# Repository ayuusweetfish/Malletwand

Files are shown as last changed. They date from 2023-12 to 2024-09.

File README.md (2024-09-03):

# Malletwand: the Pendulum as a Handheld Interface to Musical Timing

**Malletwand** is a handheld controller device in the form of a pendulum (a handle with a swinging bob), which can act as an input interface to the timing of musical playback.

We present this at [NIME](https://nime.org/) 2024 as a short paper ([PDF](paper/paper.pdf); video to-be-updated) in paper session 10, on Friday, 6 Sep.

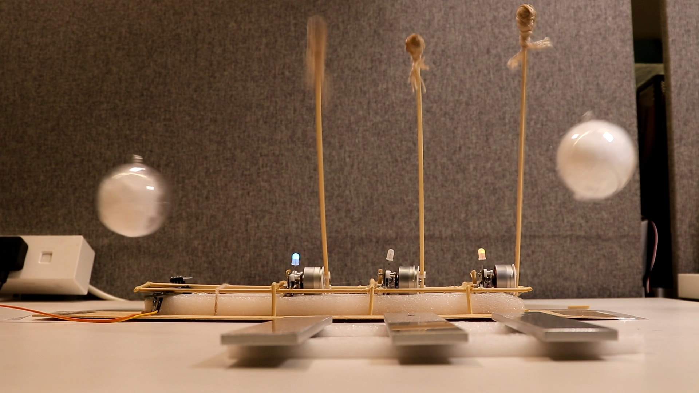
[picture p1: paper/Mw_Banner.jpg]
Banner image: the white balls of the controllers swinging in the air, in front of a prototype self-playing glockenspiel


## Contents

The following directories contain all the files for design and implementation (hardware, firmware, and mechanical).
- **wand/**: the handheld controller (the "Wand").
  - Hardware is a single PCB; firmware for the two controllers are in subdirectories **fw/** (the main one) and **fw_bob/** (the small one in the bob/ball) respectively.
- **mallet/**: one unit of the self-playing (robotic) glockenspiel instrument (the "Mallet").
- **mallet_central/**: the central unit for the instrument, mostly managing communications (both wireless and wired).

To use the files, the following software packages are required (versions for reference):
- Hardware: KiCad (7.0.10)
- Firmware: Arm GNU Toolchain (GCC 10.3.1), STM32Cube ('G0 1.5.0, 'L0 1.12.1), PlatformIO (6.1.15)
- Mechanical: FreeCAD (0.21.1), OpenSCAD (2021.01)

The following directories contain miscellaneous resources:
- **numerical/**: Numerical experiments for the filtering algorithms (EKF and ALS), implemented in Julia.
- **paper/**: The paper's LaTeX source and images.
- **testdrive/**: A testbed prototype for the sensors, created in the early days of development. Includes both hardware and firmware, and a desktop client to receive the BLE signals. Currently not well documented, but might be relevant for inspection (and visualisation?).
- **releases/**: Gerber files submitted to the PCB fabrication house.

## Licence
All content in this repository is distributed under CERN-OHL-S (CERN Open Hardware Licence Version 2, Strongly Reciprocal). See full text at **COPYING.txt** or [online](https://ohwr.org/cern_ohl_s_v2.txt).

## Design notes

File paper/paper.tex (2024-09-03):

% xelatex paper
% xelatex paper && bibtex paper && xelatex paper && xelatex paper

\documentclass{nime-alternate} % Uncomment when publishing final version

% Uncomment only one of the ones below
\usepackage{anonymize} 		   %Uncomment this line to publish
% \usepackage[blind]{anonymize}%Uncomment this line for blind review

\usepackage[utf8]{inputenc}

\usepackage{stfloats}
\usepackage{amsmath}
\usepackage{microtype}
\usepackage[hidelinks]{hyperref}

\begin{document}
\pretolerance=1000
\hyphenpenalty=100
\emergencystretch 1em

% --- Author Metadata here ---
\conferenceinfo{NIME'24,}{4--6 September, Utrecht, The Netherlands.}

\title{Malletwand: the Pendulum as a Handheld Interface to Musical Timing}

\label{key}
\numberofauthors{2}
\author{
\alignauthor
\anonymize{A.} \\
  \affaddr{\anonymize{Academy of Arts \& Design, Tsinghua University}}\\
  \affaddr{\anonymize{Beijing, China}}\\
  \email{\anonymize{claire@ayu.land}}
\alignauthor
\anonymize{H.} \\
  \affaddr{\anonymize{Academy of Arts \& Design, Tsinghua University}}\\
  \affaddr{\anonymize{Beijing, China}}\\
  \email{\anonymize{lihanxua22@mails.tsinghua.edu.cn}}
\and
\alignauthor
\anonymize{R.} \\
  \affaddr{\anonymize{Academy of Arts \& Design, Tsinghua University}}\\
  \affaddr{\anonymize{Beijing, China}}\\
  \email{\anonymize{wangrh22@mails.tsinghua.edu.cn}}
\alignauthor
\anonymize{H.} \\
  \affaddr{\anonymize{Academy of Arts \& Design, Tsinghua University}}\\
  \affaddr{\anonymize{Beijing, China}}\\
  \email{\anonymize{mhp@tsinghua.edu.cn}}
}
\date{6 February 2024}

\maketitle

\begin{figure*}[h!]
  \centering
  
  \caption{The Malletwand controllers with the prototype self-playing glockenspiel.}
  \label{fig:Banner}
\end{figure*}

\begin{abstract}
We devise and implement an interface in the form of a handheld pendulum device for manipulating the timing of musical playback. The physical properties of the pendulum make this interaction scheme steady and intuitive, and particularly suitable as an introductory means of musical engagement for untrained participants. We build a self-playing glockenspiel around this interface to demonstrate how our design encourages musical exploration and social play. We conclude by discussing potential extrapolations and integrations of the design in mobile and hybrid scenarios.
\end{abstract}
\keywords{Musical interface, pendulums, self-playing instruments, pose estimation, tactility, HCI}

\ccsdesc[500]{Applied computing~Sound and music computing}
\ccsdesc[300]{Human-centered computing~Interaction devices}
\ccsdesc[300]{Hardware~Sensor applications and deployments}
\printccsdesc

\section{Introduction}

Throughout our experience, we have always been able to capture the instinctive desire to actively and earnestly engage in music from those that have not had the advantage to experience music full-scale.
In our lasting endeavour to expand the reach of musically-meaningful interactive experiences, we set out on a search of an interaction scheme that is easy to understand and operate without musical expertise, while navigating the participant in sensible directions to manipulate the sounds to their own imagination, deepening their connection with the musical elements they have been presented with.

We settled on the periodic motion of the pendulum. The stability and self-recovering property of pendular motion make for a reliable framework of periodic musical time, i.e., tempo, or beats.

We devise and implement a controller interface, which we title the Malletwand, in the form of a handheld pendulum device (the ``wand''). By swinging the pendulum, the participant is able to feel and manipulate the speed of musical time, while the kinematic properties gently guide them through the tendency to keep a stable period, preventing excessive deviance from a steady tempo.

We imagine that this interface be paired with various types of musical actuators. For this report, we build a self-playing glockenspiel (the ``mallet'') operated by up to two such controllers in order to demonstrate how our design encourages musical exploration and social play.

The rest of the article is outlined as follows. We provide an overview of related work in various relevant fields before presenting the details of our design and implementation of the controller interface and the self-playing instrument. We go on to discuss potential extrapolations and integrations of the design in mobile and hybrid scenarios, some of which we plan as our future work. Algorithmic details are laid out in the appendix.

\section{Related work}

As we direct our design towards approachability for all levels of expertise, we look for intuitive universalities among human music, ideally natural kinesthetic and auditory stimuli that are processed and understood subconsciously. We directed our attention to the formation and perception of isochronal patterns based on the abundant argument that humans naturally tend to perceive time, and especially in the musical context, in cycles and patterns~\cite{Brower:Cog, Neisser_1976, Ravignani2016}. To paraphrase our forerunners, repeating cycles of time set the boundaries of our activities as well as form grounds on which we anticipate our sensory stimuli. Discussions went further to establish the metaphorical and cognitive interplay of our sense of time with embodied motion~\cite{Johnson_Larson_2003, Johnson_2008}.

Indeed, there have been a number of devices that manifest the link between periodic bodily movement and stable temporal patterns. Scrubbing is a standard technique for turntablists to manipulate the speed of sounds by rotating vinyl records. Hand-cranked musical boxes provide a more approachable way to drive the flow of music by one's own hands; although the Swedish band Wintergatan went as far as to build an entire machine, the Marble Machine, that turns the revolution of the manual crank into the progression of a musical piece~\cite{Rundle_Woollaston-Webber_2017}.

However, these devices share the common limitation that they require practice, or at least familarity with steady bodily movement, to prevent sounds from being distorted in the temporal domain. Laypeople tend to invoke unsteady musical time on such devices, rendering the music less understandable and aesthetically pleasing, while it remains unclear to them how they should refine their actions in the reasonable directions. Thus, they will not be able to get the most out of the tactile musical experience.

From another perspective, we are delighted to see novel musical devices that employ pendular motion or handheld physical controllers. Kugelschwung~\cite{Kugelschwung} is a digital musical instrument that relies on a set of pendulums mounted on a tabletop frame supplying control signals for soundscapes. Le Bâton~\cite{LeBaton} maps the chaotic behaviour of the triple pendulum into unpredictably varying electronic sounds. Gyrotyre~\cite{Gyrotyre}, on the other hand (no pun intended), is a handheld controller that maps oscillating signals from a gyroscope installed on a precessing wheel to various musical applications.

Still, these interfaces and instruments take larger physical forms and mainly aim at stage performances and/or dedicated experimental production setups. Our design adds to this ensemble a missing piece: a lightweight handheld controller interface that can be enjoyable and meaningful regardless of the participant's prior musical experience.

\section{The ``Wand''}

\subsection{Design Overview}
We first present the details of the handheld controller interface. It takes the form of a handle with a hanging bob (ball) that can freely swing and spin around, forming a pendulum. The participant swings the pendulum at their desired frequency while the bob's quasi-periodic motion is mapped to continuous musical time such that each fastest-moving point in a period corresponds to the start of a beat. (This point is usually perceived to be the ``central'' or the ``lowest'' point in simple pendulums, but since ours has an extra degree of freedom, i.e., is a spherical pendulum, this appointment needs to be extrapolated.) Such generated timing signals are wirelessly transmitted to an actuator, such as a self-playing instrument, that plays a piece of music according to the manipulated flow of musical time.

We add a few simple features to enrich the feedback and the interaction. Haptic feedback at beat onsets is provided by a vibration motor. A tri-colour LED is placed inside the bob that is flexible in its responses to interaction, e.g., it may indicate the changing beats by alternating tints or identify the voice by colour coding in the case of multiplayer interaction. Furthermore, the controller is intended to be normally at rest, so it is equipped with a tilt sensor that wakes up the entire circuit from sleep when the device is picked up by a participant. A single-pole, single-throw (SPST) switch allows the overall power to be turned off during times without participants.

\subsection{Construction}
We design customised electronics for all of our devices. In addition to the aforementioned components, the handle contains a lithium polymer (Li-Po) battery, a microcontroller, and a radio transceiver; the bob contains a separate low-power microcontroller and MEMS chips that form a 9-axis IMU (an accelerometer, a gyroscope, and a geomagnetometer). The complete structure is illustrated in Figure~\ref{fig:WandConstruction}.

\begin{figure*}[t!]
  \centering
  
  \caption{(a) Photo of the assembled circuit board before being cut. (b) Photo of the assembled wand with the casing and the bob. (c) Block diagram of the electronic components involved.}
  \label{fig:WandConstruction}
\end{figure*}

The board is fabricated as one, in order to ease soldering and debugging as we build the prototype. After testing is complete, we cut the board at the thin connection (in Figure~\ref{fig:WandConstruction}a) and connect the two parts with soldered thin wires (3 strands of 32 AWG, establishing an asynchronous USART connection). The handle part is glued inside a 3D-printed casing with the wires hanging down onto the bob part (Figure~\ref{fig:WandConstruction}b), which is inserted onto a holder made of polymeric foam glued in a translucent plastic sphere filled with down cotton. We add fishing wires to strengthen the connection and prevent the electric wires from excessive tension and fatigue.

\subsection{Estimation Algorithm}
All processing is done on the microcontroller device. The microcontroller we used, STM32G0, is an Arm Cortex-M0+ processor without a dedicated FPU, but our complete algorithm runs well within its 64 MHz system clock with software floating-point arithmetic.

The algorithm requires an initial reference frame calibration, run once after assembly. An ensemble of filters is then employed to process the sensor signals. We introduce these steps respectively. To keep our description concise, we defer all of the mathematical details to Appendix~\ref{appendix:signal-processing}.

\subsubsection{Reference frame calibration}
After assembly, the tilted orientation of the circuit board inside the bob should be compensated for.

The calibration is initiated by a manually-issued wireless radio signal. The operator is then expected to hold the handle and let the bob stay stationary for a short while. Signals from the accelerometer are continuously monitored until they reach a sufficiently low deviation throughout a fixed time window of 3 seconds. This yields an axis vector that acts as the reference for future motion estimation from sensor readings which is saved in the persistent flash storage of the microcontroller. For details, please refer to Appendix~\ref{appendix:calib-ori}.

\subsubsection{Magnetometer calibration}
As our algorithm relies on the geomagnetometer to improve the accuracy of pose estimation, the distortion of the ambient magnetic field should also be compensated. Since indoor environments contain prominent and variable magnetic interference, this calibration is done in real time during operation. This works by continuously collecting the readings of the magnetometer and finding an ellipsoid fit that tries to distort the collected data in the form of 3D vectors onto a unit sphere. We employ the adjusted least squares estimator introduced by \cite{Markovsky_2004_ALS} with complementary steps by \cite{Renaudin2010}.

\subsubsection{Motion signal processing}
Our IMU produces readings at a sampling rate of 100 Hz, and the filtering algorithms run at the same rate. At each time step, we first estimate the facing of the bob through a complementary filter, inspired by~\cite{Min_Complementary}, combining signals from the gyroscope and the magnetometer. The result is turned into a rotational transform that cancels out the bob's rotation around its own axis. Sensor readings adjusted by this transform are then fed into an extended Kalman filter (EKF) that estimates the trajectory of the bob in 3D space, and more importantly, its current phase within the period of motion. This is the value that gets interpreted as the driving signal of musical time, and is transmitted to the actuator.

A confidence indicator is derived from the Frobenius norm of the estimation covariance matrix in the EKF. This value is used to avoid muddled time progression when the motion is not stably periodic, e.g., during the first few seconds since the beginning of interaction.

\section{The ``Mallets''}

\begin{figure*}[bh!]
  \centering
  
  \caption{(a) Overall photo of the instrument. (b) Close-up of a single sub-unit. (c) Block diagram of the electronic components involved.}
  \label{fig:MalletConstruction}
\end{figure*}

\subsection{Design Overview}
Our self-playing instrument is a robotic glockenspiel. We use a 3-key prototype for demonstrative purposes, but an extension of register requires no change in implementation.

The instrument is accompanied by two Malletwand controllers and can operate in both solo and co-operative mode. Signals received from the controllers drive the musical time in a preprogrammed piece, similar to a musical box. Co-operative mode is entered by two controllers being operated simultaneously, where each controller corresponds to one voice (part) indicated by colours of the lights. The music only progresses when the motion of the two are roughly in synchronisation.

\subsection{Construction}
\subsubsection{Keys}
The keys are laser-cut from aluminum of 5 mm thickness. We chose aluminum instead of an alloy since we would like a mellower timbre. Prior to production, we ordered a small number of samples from the fabricator to determine the acoustic characteristics of the material. The resonant frequency of a vibrating metal bar is inversely proportional to the square root of its length; we thus calculate the desired lengths according to equal-temperament tuning, create the blueprints programmatically in OpenSCAD and send them for fabrication.

\subsubsection{Electronics}
The electronics of the instrument comprise a main unit and multiple sub-units, one for each key. The main unit is responsible for the communication with the controller(s) as well as the delivery of power and control signals to the sub-units. Each sub-unit has a small brushless DC (BLDC) motor that holds a yarn mallet, fixed onto a circuit board bearing a magnetic encoder, a tri-colour LED, and a microcontroller carrying out vector control. The entire device is powered by a single DC supply between 9~V and 25~V into the main unit. The complete structure is illustrated in Figure~\ref{fig:MalletConstruction}.

We choose I\textsuperscript{2}C as the communication protocol, requiring only two electrical signals for multiple parallel devices. We use an I\textsuperscript{2}C accelerator chip on the main unit to mitigate the rise time issue due to increased bus capacitance of long transmission wires.

\subsubsection{Mechanical and miscellaneous}
We fix all units (both the main one and sub-units) onto polymeric foam which is glued onto a thin wooden board that serves as the base. Slots created on the foam hold the units as well as the electrical lines. We glue an extra frame made of wooden sticks around the foam to improve stability.

The mechanical parts for the fixation of motors and mallets are 3D-printed in PLA and installed with screws. Yarn on the mallets is manually wrapped around a wooden core and slightly melted with a lighter in order to tighten it.

\subsection{Performance}
During operation, the glockenspiel plays a tune as the pendulums swing back and forth. The tempo of the music adjusts to the period of pendular motion. Haptic feedback and lights on both the bob and the keys add tactility and visualisation to the embodied musical experience. Figure~\ref{fig:Banner} is a photo of the instrument in action.

Please refer to the demonstration video for a performance recording.

\section{Discussion}

\subsection{The Experience of Malletwand}
Our design accomplished our initial goals. The algorithms yield a reliable estimation of motion, successfully running the glockenspiel through a tune steadily with little external intervention on the pendulum, while being able to respond reasonably fast to changes in motion (within 1\textasciitilde{}2 swings). We enjoyed our own work.

Our pilot study with outside participants was preliminary, but sufficient to bring forth a few insights. We confirmed that the pendulum-based interface is appreciated for its accuracy and ease of use. First-time users might not instantly figure out how to reliably manipulate the speed (period) of the pendulum, but were able to do so with their own exploration or with a hint. Since participants were able to quickly grasp the mapping logic and its control, musical exploration was instantly opened up to them. Participants tended to experiment with extremes before resorting to a steady tempo, trying gentler articulations. They considered the interaction intuitive and manageable, and reported being generally successful in their pursuit of musical engagement and expression.

Social play is encouraged through the attempts to synchronise between the duo. This resembles the experience of musicians in ensembles, orchestras, or bands, and is appreciated by such practitioners. However, we notice that this is a rare and precious chance for participants with less musical experiences, and we hope to bring such meaningful and joyful activities to their reach through our design. We are still yet to conduct more extensive studies with such participants.

One major shortcoming of the co-operative mode is the difficulty to synchronise the phases between the duo, due to inertia preventing quick changes in speed, even more so regarding phase and position. This has the benefit of extending conversations and explorations between participants, but the less experienced of them might not figure out effective ways quickly and intuitively. In this regard, we are considering improving on the co-operative play mode, either by revamping the interaction rules or by extra hints in the form of synchronised haptic feedback or textual hints.

\subsection{Extrapolations and Future Work}
As we have written in the Introduction section, we imagine that this interface not be limited to our glockenspiel instrument. Any device that plays music can employ a pendulum interface to invite participants into musical time. Hybrid formats, including projections and mappings, or musical devices remotely incited beyond kilometers, open doors to tactility in a hybrid world.

Other musical features or temporal formats, or even spatial expositions, may be involved as well. What about an installation that gives procedurally generated sounds? What about a film? A dance? A video game where cats chase the wand? A revolving kaleidoscope or a planetarium?

The estimation algorithms in the pendulum enable it to act as a standalone sensor, adding to the toolkit of digital artistic expression. What about an electronic mimicry of a windbell? A big hanging simulated telescope? A sparkling earring?

Another possible extrapolation lies in the mobile scenario. The sensors we used are standard in today's smartphones, and relevant APIs are readily available on modern web browsers. Thus, with the processing algorithms ported to JavaScript, websites will be able to create novel interactive experiences without special equipment, simply by asking the visitor to put their phone in a holder, attach a string, and swing it to their liking. What about such a musical box? We leave all these for the reader as exercises while we try our hands on a few.

\section{Conclusion}
Malletwand is our first step in spreading the enjoyability of music through a tactile medium. It is to our delight to have implemented the system and seeing it bear the unique approachability and adaptability to varied levels of musical expertise, adding to the state-of-the-art repertoire of physical-system controller interfaces. We realise that this interface has the potential to adapt to more instruments and scenarios, and put forward what we have envisaged. We share our work in the hope that our methods and insights can be useful to those who share the aspirations with us.

\section{Ethical Statement}
This research does not involve processes or experiments that might raise ethical concerns. In addition, the authors have made conscious efforts to abide by the NIME ethical guidelines.

\section{Acknowledgments}
We would like to thank the anonymous reviewers for their valuable feedback. We would like to extend our gratitude towards Yao Zhihao for the enthusiastic help in handicraft work; and to Dr Mier, for offering aid in mathematical concepts. A special acknowledgement goes to Tsinghua University Symphonic Band, without which this motif would not have developed.

\bibliographystyle{abbrv}
\bibliography{nime-references} 

\appendix
\section{Details of the Signal Processing Algorithms}
\label{appendix:signal-processing}
We try to outline the mathematical derivations of the algorithms. For details, please refer to the source code.

\subsection{Calibration}
\subsubsection{Reference frame}
\label{appendix:calib-ori}
An accelerometer reading is a 3-dimensional vector. When a sufficiently low variation of readings is achieved during calibration, their average vector is normalized and taken as the reference axis $\mathbf{u}$. We find a quaternion $\mathbf{q}$ that rotates this vector to the $+z$ unit vector, $\mathbf{z}^+ = \begin{bmatrix} 0 & 0 & 1 \end{bmatrix}^\mathsf{T}$. This is achieved by setting $\mathbf{q}_1 = \begin{bmatrix} \mathbf{u} \times \mathbf{z^+} & (1 + \mathbf{u} \cdot \mathbf{z^+}) \end{bmatrix}$ and $\mathbf{q} = \mathbf{q}_1 \mathbin{\mathop{/}} \lvert \mathbf{q}_1 \rvert$.

This quaternion $\mathbf{q}$ transforms the reference frame of the accelerometer such that the $xy$ plane corresponds to the local ground, whose normal vector is the $z$ axis. The rotation specified by $\mathbf{q}$ is applied to future raw accelerometer readings $\tilde{\mathbf{a}}$ and gyroscope readings $\tilde{\mathbf{g}}$, assuming that their reference frames are aligned, to yield a carlibrated 6-axis reading:
$\mathbf{a} = \mathbf{q} \tilde{\mathbf{a}} \mathbf{q}^{-1}$, $\mathbf{g} = \mathbf{q} \tilde{\mathbf{g}} \mathbf{q}^{-1}$.

\subsubsection{Magnetometer}
\label{appendix:calib-mag}
This task can be formulated as follows: given a set of 3-dimensional vectors $\{ \tilde{\mathbf{m}}_i \}$, find an affine transform $(\mathbf{Q}, \mathbf{o})$ such that the set of $\{\mathbf{Q} \tilde{\mathbf{m}}_i + \mathbf{o}\}$ best fits onto a unit sphere.

We follow the method of \cite{Renaudin2010}, employing the ALS estimator in \cite{Markovsky_2004_ALS} to find a fit $(\mathbf{A}, \mathbf{c})$ to the set of equations
$(\tilde{\mathbf{m}}_i - \mathbf{c})^\mathsf{T} \mathbf{A} (\tilde{\mathbf{m}}_i - \mathbf{c}) = 1$
and then calculating an inverse transform that converts this ellipsoid back to the unit sphere.

Since the ALS estimator only requires an accumulated matrix $\mathbf{\Psi}$ and not the individual values of $\tilde{\mathbf{m}}_i$, we are able to carry out the calculation continuously with constant rather than linear memory consumption.

\subsection{Estimation}
\subsubsection{Facing}
\label{appendix:est-facing}
We treat the 2-dimensional orientation angle on the $xy$ plane as the value being estimated. The calibrated magnetometer provides a proportional signal $\varphi$, while the calibrated gyroscope provides a derivative signal $\dot\varphi$.
The input signals are given by $\varphi = -\mathop{\mathrm{arctan}} \frac {\mathbf{m}_y} {\mathbf{m}_x}$ and $\dot\varphi = \mathrm{d}{\mathbf{g}_y} \mathbin{\mathop{/}} \mathrm{d}t$. Here $\mathbf{m}$ is the calibrated and aligned magnetometer reading,
\begin{equation*}\label{eqn:est-facing}
\mathbf{m} = \mathbf{q} \ (\mathbf{Q}\tilde{\mathbf{m}} + \mathbf{o}) \ \mathbf{q}^{-1}\text{,}
\end{equation*}
and $\mathbf{g}$ is the calibrated gyroscope reading as is mentioned in section~\ref{appendix:calib-ori}.

Following the design in~\cite{Min_Complementary}, we construct a complementary filter by the transfer equation
\begin{equation*}
\begin{split}
& \hat{\varphi} = \frac 1 {s^2 + k_\mathrm{p} s + k_\mathrm{i}} \left( s \dot\varphi + (k_\mathrm{p} s + k_\mathrm{i}) \varphi \right) \text{,} \\
& k_\mathrm{p} = \frac {\omega_0} {Q_\mathrm{P}},\qquad k_\mathrm{i} = \omega_0^2\text{.}
\end{split}
\end{equation*}
This filter yields an estimation $\hat{\varphi}$ balancing between the two signals.
We fix the pole quality factor as $Q_\mathrm{P} = 1 \mathbin{\mathop{/}} \sqrt{2}$ and empirically tune the corner frequency at $\omega_0 = 24\ \text{rad/s} \approx 3.8\ \text{Hz}$.

\subsubsection{Motion}
\label{appendix:est-motion}
In the extended Kalman filter we formulate the state vector as $\mathbf{x} = \begin{bmatrix} \omega & A & \theta & B & \phi \end{bmatrix}^\mathsf{T}$, charactising an elliptical orbit around the origin --- the ideal observation $\mathbf{z} = \begin{bmatrix} A \cos \theta & B \cos (\theta + \phi) \end{bmatrix}^\mathsf{T}$ is compared against the gyroscope readings adjusted by the facing estimation,
\begin{equation*}
\begin{split}
\hat{\mathbf{g}}' &= \mathbf{r}_{z, \theta} \hat{\mathbf{g}} \mathbf{r}_{z, \theta}^{-1} \\
\text{where}\quad \mathbf{r}_{z, \theta} &= \begin{bmatrix} 0 & 0 & \sin \frac \theta 2 & \cos \frac \theta 2 \end{bmatrix}
\text{,}
\end{split}
\end{equation*}
projected onto the $xy$ plane. Varying $\theta$ over $[0, 2\pi)$ traces out an elliptic trajectory of this point and $\theta$ is the current phase within the period. $\omega$ is the rate of change of phase, $\mathrm{d}{\theta} \mathbin{\mathop{/}} \mathrm{d}t$, thus the prediction function is
\begin{equation*}
f(\mathbf{x}) = \begin{bmatrix} \omega & A & \theta + \omega \Delta t & B & \phi \end{bmatrix}^\mathsf{T}\text{.}
\end{equation*}
The process noise covariance matrix is set to be a diagonal matrix with the first entry prominently larger than the others, since $\omega$ is actively changed by the participant. % $A, \theta, B, \phi$ are assigned smaller process noise variances so that the filter does not get stuck in a local optimum where all parameters oscillate, altogether stopping the steady progress of phase.

After the estimations of $A, \theta, B, \phi$ are obtained, we find the corresponding parameter $\theta$ at the major axis (which is also the fastest-moving point) by
\begin{equation*}
\theta_0 = \frac 1 2 \mathop{\mathrm{arctan}} \frac {A^2 + B^2 \cos 2\phi} {B^2 \sin 2\phi} + \frac 1 4 \pi\text{,}
\end{equation*}
and report the difference $\theta - \theta_0$ as the final output, so that an output phase of zero aligns with this fastest-moving point.

\section{Source Repository}
All of our design files (printed circuit board assemblies, mechanical models) and source code, as well as extended documentation and demonstrations, are published at \newline \anonymize{\texttt{https://github.com/ayuusweetfish/Malletwand}}.

\end{document}

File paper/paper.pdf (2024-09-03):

# Malletwand: the Pendulum as a Handheld Interface to Musical Timing

A.

### Academy of Arts & Design, Tsinghua University Beijing, China claire@ayu.land

H.

### Academy of Arts & Design, Tsinghua University Beijing, China lihanxua22@mails.tsinghua.edu.cn

R.

### Academy of Arts & Design, Tsinghua University Beijing, China wangrh22@mails.tsinghua.edu.cn

H.

### Academy of Arts & Design, Tsinghua University Beijing, China mhp@tsinghua.edu.cn

## ABSTRACT

We devise and implement an interface in the form of a handheld pendulum device for manipulating the timing of musical playback. The physical properties of the pendulum make this interaction scheme steady and intuitive, and particularly suitable as an introductory means of musical engagement for untrained participants. We build a self-playing glockenspiel around this interface to demonstrate how our design encourages musical exploration and social play. We conclude by discussing potential extrapolations and integrations of the design in mobile and hybrid scenarios.

## Author Keywords

Musical interface, pendulums, self-playing instruments, pose estimation, tactility, HCI

## CCS Concepts

•Applied computing → Sound and music computing; •Humancentered computing → Interaction devices; •Hardware → Sensor applications and deployments;

## 1. INTRODUCTION

Throughout our experience, we have always been able to capture the instinctive desire to actively and earnestly engage in music from those that have not had the advantage to experience music full-scale. In our lasting endeavour to expand the reach of musically-meaningful interactive experiences, we set out on a search of an interaction scheme that is easy to understand and operate without musical expertise, while navigating the participant in sensible directions to manipulate the sounds to their own imagination, deepening their connection with the musical elements they have been presented with.
We settled on the periodic motion of the pendulum. The stability and self-recovering property of pendular motion

Licensed under a Creative Commons Attribution 4.0 International License (CC BY 4.0). Copyright remains with the author(s).
NIME’24, 4–6 September, Utrecht, The Netherlands.

make for a reliable framework of periodic musical time, i.e., tempo, or beats.
We devise and implement a controller interface, which we title the Malletwand, in the form of a handheld pendulum device (the “wand”). By swinging the pendulum, the participant is able to feel and manipulate the speed of musical time, while the kinematic properties gently guide them through the tendency to keep a stable period, preventing excessive deviance from a steady tempo.
We imagine that this interface be paired with various types of musical actuators. For this report, we build a self-playing glockenspiel (the “mallet”) operated by up to two such controllers in order to demonstrate how our design encourages musical exploration and social play.
The rest of the article is outlined as follows. We provide an overview of related work in various relevant fields before presenting the details of our design and implementation of the controller interface and the self-playing instrument. We go on to discuss potential extrapolations and integrations of the design in mobile and hybrid scenarios, some of which we plan as our future work. Algorithmic details are laid out in the appendix.

## 2. RELATED WORK

As we direct our design towards approachability for all levels of expertise, we look for intuitive universalities among human music, ideally natural kinesthetic and auditory stimuli that are processed and understood subconsciously. We directed our attention to the formation and perception of isochronal patterns based on the abundant argument that humans naturally tend to perceive time, and especially in the musical context, in cycles and patterns [1, 7, 8]. To paraphrase our forerunners, repeating cycles of time set the boundaries of our activities as well as form grounds on which we anticipate our sensory stimuli. Discussions went further to establish the metaphorical and cognitive interplay of our sense of time with embodied motion [4, 3].
Indeed, there have been a number of devices that manifest the link between periodic bodily movement and stable temporal patterns. Scrubbing is a standard technique for turntablists to manipulate the speed of sounds by rotating vinyl records. Hand-cranked musical boxes provide a more approachable way to drive the flow of music by one’s own hands; although the Swedish band Wintergatan went as far as to build an entire machine, the Marble Machine, that turns the revolution of the manual crank into the progression of a musical piece [10].
However, these devices share the common limitation that they require practice, or at least familarity with steady


Figure 1: The Malletwand controllers with the prototype self-playing glockenspiel.

bodily movement, to prevent sounds from being distorted in the temporal domain. Laypeople tend to invoke unsteady musical time on such devices, rendering the music less understandable and aesthetically pleasing, while it remains unclear to them how they should refine their actions in the reasonable directions. Thus, they will not be able to get the most out of the tactile musical experience.
From another perspective, we are delighted to see novel musical devices that employ pendular motion or handheld physical controllers. Kugelschwung [2] is a digital musical instrument that relies on a set of pendulums mounted on a tabletop frame supplying control signals for soundscapes. Le Bˆaton [12] maps the chaotic behaviour of the triple pendulum into unpredictably varying electronic sounds. Gyrotyre [11], on the other hand (no pun intended), is a handheld controller that maps oscillating signals from a gyroscope installed on a precessing wheel to various musical applications.
Still, these interfaces and instruments take larger physical forms and mainly aim at stage performances and/or dedicated experimental production setups. Our design adds to this ensemble a missing piece: a lightweight handheld controller interface that can be enjoyable and meaningful regardless of the participant’s prior musical experience.

## 3. THE “WAND”

## 3.1 Design Overview

We first present the details of the handheld controller interface. It takes the form of a handle with a hanging bob (ball) that can freely swing and spin around, forming a pendulum. The participant swings the pendulum at their desired frequency while the bob’s quasi-periodic motion is mapped to continuous musical time such that each fastest-moving point in a period corresponds to the start of a beat. (This point is usually perceived to be the “central” or the

“lowest” point in simple pendulums, but since ours has an extra degree of freedom, i.e., is a spherical pendulum, this appointment needs to be extrapolated.) Such generated timing signals are wirelessly transmitted to an actuator, such as a self-playing instrument, that plays a piece of music according to the manipulated flow of musical time.
We add a few simple features to enrich the feedback and the interaction. Haptic feedback at beat onsets is provided by a vibration motor. A tri-colour LED is placed inside the bob that is flexible in its responses to interaction, e.g., it may indicate the changing beats by alternating tints or identify the voice by colour coding in the case of multiplayer interaction. Furthermore, the controller is intended to be normally at rest, so it is equipped with a tilt sensor that wakes up the entire circuit from sleep when the device is picked up by a participant. A single-pole, single-throw (SPST) switch allows the overall power to be turned off during times without participants.

## 3.2 Construction

We design customised electronics for all of our devices. In addition to the aforementioned components, the handle contains a lithium polymer (Li-Po) battery, a microcontroller, and a radio transceiver; the bob contains a separate lowpower microcontroller and MEMS chips that form a 9-axis IMU (an accelerometer, a gyroscope, and a geomagnetometer). The complete structure is illustrated in Figure 2. The board is fabricated as one, in order to ease soldering and debugging as we build the prototype. After testing is complete, we cut the board at the thin connection (in Figure 2a) and connect the two parts with soldered thin wires (3 strands of 32 AWG, establishing an asynchronous USART connection). The handle part is glued inside a 3D-printed casing with the wires hanging down onto the bob part (Figure 2b), which is inserted onto a holder made of polymeric foam glued in a translucent plastic sphere filled

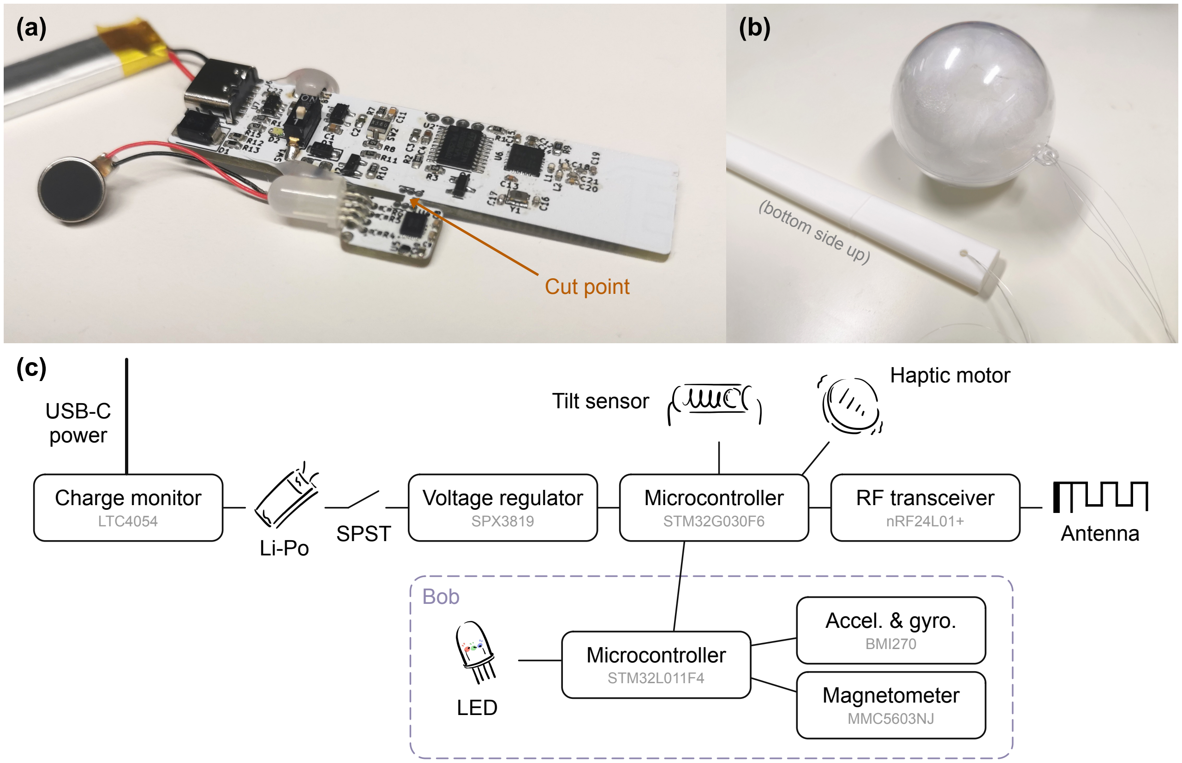
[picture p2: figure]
Microcontroller; STM32G030F6; Charge monitor; LTC4054; RF transceiver; nRF24L01+; Accel. & gyro.; BMI270; Magnetometer; MMC5603NJ; Voltage regulator SPX3819 SPST Li-Po; LED; Haptic motor; Tilt sensor; Cut point; USB-C power; Bob; STM32L011F4; Antenna; (bot om side up)

Figure 2: (a) Photo of the assembled circuit board before being cut. (b) Photo of the assembled wand with the casing and the bob. (c) Block diagram of the electronic components involved.

with down cotton. We add fishing wires to strengthen the connection and prevent the electric wires from excessive tension and fatigue.

## 3.3 Estimation Algorithm

All processing is done on the microcontroller device. The microcontroller we used, STM32G0, is an Arm Cortex-M0+ processor without a dedicated FPU, but our complete algorithm runs well within its 64 MHz system clock with software floating-point arithmetic.
The algorithm requires an initial reference frame calibration, run once after assembly. An ensemble of filters is then employed to process the sensor signals. We introduce these steps respectively. To keep our description concise, we defer all of the mathematical details to Appendix A.

### 3.3.1 Reference frame calibration

After assembly, the tilted orientation of the circuit board inside the bob should be compensated for.
The calibration is initiated by a manually-issued wireless radio signal. The operator is then expected to hold the handle and let the bob stay stationary for a short while. Signals from the accelerometer are continuously monitored until they reach a sufficiently low deviation throughout a fixed time window of 3 seconds. This yields an axis vector that acts as the reference for future motion estimation from sensor readings which is saved in the persistent flash storage of the microcontroller. For details, please refer to Appendix A.1.1.

### 3.3.2 Magnetometer calibration

As our algorithm relies on the geomagnetometer to improve the accuracy of pose estimation, the distortion of the ambient magnetic field should also be compensated. Since indoor environments contain prominent and variable magnetic interference, this calibration is done in real time during operation. This works by continuously collecting the readings of the magnetometer and finding an ellipsoid fit that tries to distort the collected data in the form of 3D vectors onto a unit sphere. We employ the adjusted least squares estimator introduced by [5] with complementary steps by [9].

### 3.3.3 Motion signal processing

Our IMU produces readings at a sampling rate of 100 Hz, and the filtering algorithms run at the same rate. At each time step, we first estimate the facing of the bob through a complementary filter, inspired by [6], combining signals from the gyroscope and the magnetometer. The result is turned into a rotational transform that cancels out the bob’s rotation around its own axis. Sensor readings adjusted by this transform are then fed into an extended Kalman filter (EKF) that estimates the trajectory of the bob in 3D space, and more importantly, its current phase within the period of motion. This is the value that gets interpreted as the driving signal of musical time, and is transmitted to the actuator.
A confidence indicator is derived from the Frobenius norm of the estimation covariance matrix in the EKF. This value is used to avoid muddled time progression when the motion is not stably periodic, e.g., during the first few seconds since the beginning of interaction.

## 4. THE “MALLETS”

## 4.1 Design Overview

Our self-playing instrument is a robotic glockenspiel. We use a 3-key prototype for demonstrative purposes, but an extension of register requires no change in implementation. The instrument is accompanied by two Malletwand controllers and can operate in both solo and co-operative mode. Signals received from the controllers drive the musical time in a preprogrammed piece, similar to a musical box. Co-operative mode is entered by two controllers being operated simultaneously, where each controller corresponds to one voice (part) indicated by colours of the lights. The music only progresses when the motion of the two are roughly in synchronisation.

## 4.2 Construction

### 4.2.1 Keys

The keys are laser-cut from aluminum of 5 mm thickness. We chose aluminum instead of an alloy since we would like a mellower timbre. Prior to production, we ordered a small number of samples from the fabricator to determine the acoustic characteristics of the material. The resonant frequency of a vibrating metal bar is inversely proportional to the square root of its length; we thus calculate the desired lengths according to equal-temperament tuning, create the blueprints programmatically in OpenSCAD and send them for fabrication.

### 4.2.2 Electronics

The electronics of the instrument comprise a main unit and multiple sub-units, one for each key. The main unit is responsible for the communication with the controller(s) as well as the delivery of power and control signals to the sub-units. Each sub-unit has a small brushless DC (BLDC) motor that holds a yarn mallet, fixed onto a circuit board bearing a magnetic encoder, a tri-colour LED, and a microcontroller carrying out vector control. The entire device is powered by a single DC supply between 9 V and 25 V into the main unit. The complete structure is illustrated in Figure 3.
We choose I²C as the communication protocol, requiring only two electrical signals for multiple parallel devices. We use an I²C accelerator chip on the main unit to mitigate the rise time issue due to increased bus capacitance of long transmission wires.

### 4.2.3 Mechanical and miscellaneous

We fix all units (both the main one and sub-units) onto polymeric foam which is glued onto a thin wooden board that serves as the base. Slots created on the foam hold the units as well as the electrical lines. We glue an extra frame made of wooden sticks around the foam to improve stability. The mechanical parts for the fixation of motors and mallets are 3D-printed in PLA and installed with screws. Yarn on the mallets is manually wrapped around a wooden core and slightly melted with a lighter in order to tighten it.

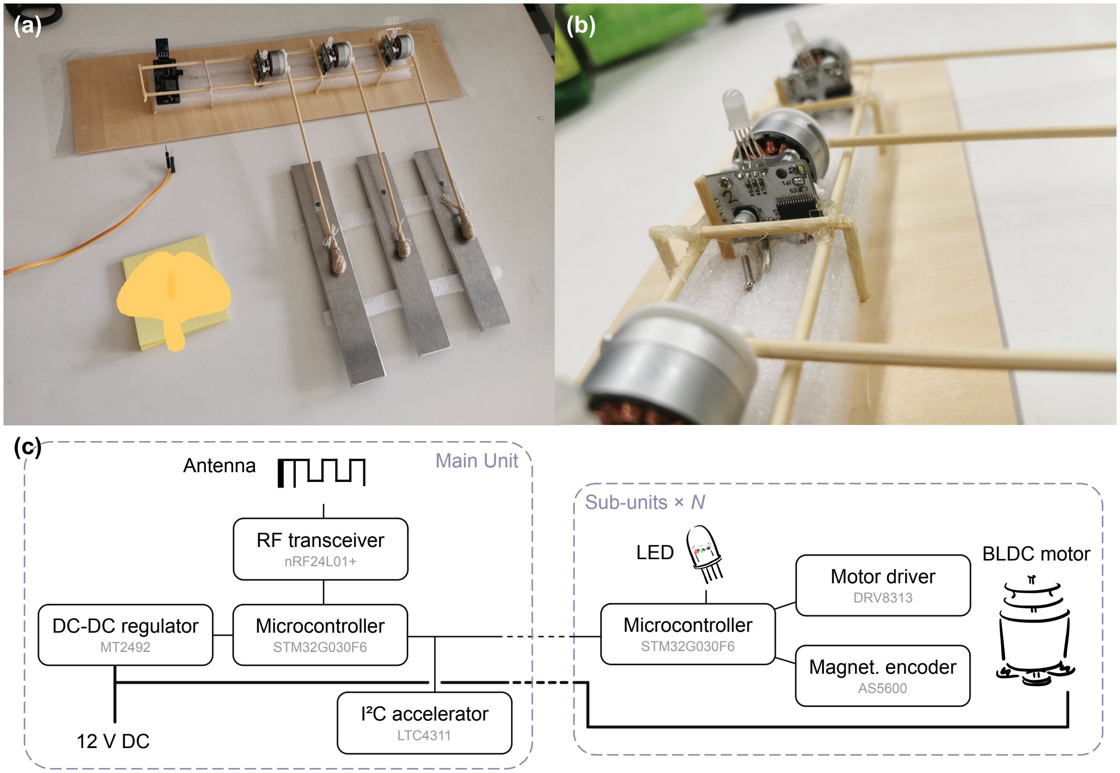
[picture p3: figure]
Microcontroller; STM32G030F6; RF transceiver; nRF24L01+; DC-DC regulator; I²C accelerator; LTC4311; Antenna; Motor driver; DRV8313; Magnet. encoder; LED; Sub-units × N; BLDC motor; Main Unit (c)

Figure 3: (a) Overall photo of the instrument. (b) Close-up of a single sub-unit. (c) Block diagram of the electronic components involved.

## 4.3 Performance

During operation, the glockenspiel plays a tune as the pendulums swing back and forth. The tempo of the music adjusts to the period of pendular motion. Haptic feedback and lights on both the bob and the keys add tactility and visualisation to the embodied musical experience. Figure 1 is a photo of the instrument in action.
Please refer to the demonstration video for a performance recording.

## 5. DISCUSSION

## 5.1 The Experience of Malletwand

Our design accomplished our initial goals. The algorithms yield a reliable estimation of motion, successfully running the glockenspiel through a tune steadily with little external intervention on the pendulum, while being able to respond reasonably fast to changes in motion (within 1˜2 swings). We enjoyed our own work.
Our pilot study with outside participants was preliminary, but sufficient to bring forth a few insights. We confirmed that the pendulum-based interface is appreciated for its accuracy and ease of use. First-time users might not instantly figure out how to reliably manipulate the speed (period) of the pendulum, but were able to do so with their own exploration or with a hint. Since participants were able to quickly grasp the mapping logic and its control, musical exploration was instantly opened up to them. Participants tended to experiment with extremes before resorting to a steady tempo, trying gentler articulations. They considered the interaction intuitive and manageable, and reported being generally successful in their pursuit of musical engagement and expression.
Social play is encouraged through the attempts to synchronise between the duo. This resembles the experience of musicians in ensembles, orchestras, or bands, and is appreciated by such practitioners. However, we notice that this is a rare and precious chance for participants with less musical experiences, and we hope to bring such meaningful and joyful activities to their reach through our design. We are still yet to conduct more extensive studies with such participants.
One major shortcoming of the co-operative mode is the difficulty to synchronise the phases between the duo, due to inertia preventing quick changes in speed, even more so regarding phase and position. This has the benefit of extending conversations and explorations between participants, but the less experienced of them might not figure out effective ways quickly and intuitively. In this regard, we are considering improving on the co-operative play mode, either by revamping the interaction rules or by extra hints in the form of synchronised haptic feedback or textual hints.

## 5.2 Extrapolations and Future Work

As we have written in the Introduction section, we imagine that this interface not be limited to our glockenspiel instrument. Any device that plays music can employ a pendulum interface to invite participants into musical time. Hybrid formats, including projections and mappings, or musical devices remotely incited beyond kilometers, open doors to tactility in a hybrid world.
Other musical features or temporal formats, or even spatial expositions, may be involved as well. What about an installation that gives procedurally generated sounds? What about a film? A dance? A video game where cats chase the wand? A revolving kaleidoscope or a planetarium? The estimation algorithms in the pendulum enable it to act as a standalone sensor, adding to the toolkit of digital artistic expression. What about an electronic mimicry of a windbell? A big hanging simulated telescope? A sparkling earring?
Another possible extrapolation lies in the mobile scenario. The sensors we used are standard in today’s smartphones, and relevant APIs are readily available on modern web browsers. Thus, with the processing algorithms ported to JavaScript, websites will be able to create novel interactive experiences without special equipment, simply by asking the visitor to put their phone in a holder, attach a string, and swing it to their liking. What about such a musical box? We leave all these for the reader as exercises while we try our hands on a few.

## 6. CONCLUSION

Malletwand is our first step in spreading the enjoyability of music through a tactile medium. It is to our delight to have implemented the system and seeing it bear the unique approachability and adaptability to varied levels of musical expertise, adding to the state-of-the-art repertoire of physical-system controller interfaces. We realise that this interface has the potential to adapt to more instruments and scenarios, and put forward what we have envisaged. We share our work in the hope that our methods and insights can be useful to those who share the aspirations with us.

## 7. ETHICAL STATEMENT

This research does not involve processes or experiments that might raise ethical concerns. In addition, the authors have made conscious efforts to abide by the NIME ethical guidelines.

## 8. ACKNOWLEDGMENTS

We would like to thank the anonymous reviewers for their valuable feedback. We would like to extend our gratitude towards Yao Zhihao for the enthusiastic help in handicraft work; and to Dr Mier, for offering aid in mathematical concepts. A special acknowledgement goes to Tsinghua University Symphonic Band, without which this motif would not have developed.

## 9. REFERENCES

[1] C. Brower. A cognitive theory of musical meaning. Journal of Music Theory, 44(2):323–379, 2000.
[2] J. Henson, B. Collins, A. Giles, K. Webb,
M. Livingston, and T. Mortensson. Kugelschwung - a pendulum-based musical instrument. In Proceedings of the International Conference on New Interfaces for Musical Expression, Ann Arbor, Michigan, 2012. University of Michigan.
[3] M. Johnson. The meaning of the body: Aesthetics of human understanding. University of Chicago Press, Chicago, IL, 2008.
[4] M. L. Johnson and S. Larson. ”something in the way she moves”-metaphors of musical motion. Metaphor and Symbol, 18(2):63–84, 2003.
[5] I. Markovsky, A. Kukush, and S. Huffel. Consistent least squares fitting of ellipsoids. Numerische Mathematik, 98, 07 2004.
[6] H. G. Min and E. T. Jeung. Complementary filter design for angle estimation using mems accelerometer and gyroscope. https://www.academia.edu/6261055 (accessed 2024-02-07).
[7] U. Neisser. Cognition and Reality: Principles and Implications of Cognitive Psychology. W.H. Freeman, New York, NY, 1976.
[8] A. Ravignani, T. Delgado, and S. Kirby. Musical evolution in the lab exhibits rhythmic universals. Nature Human Behaviour, 1(1):0007, Dec 2016.
[9] V. Renaudin, M. H. Afzal, and G. Lachapelle. Complete triaxis magnetometer calibration in the magnetic domain. Journal of Sensors, 2010:967245, Dec 2010.
[10] M. Rundle and V. Woollaston-Webber. 16 months to build, two hours to demolish: watch the marble machine being taken apart, Mar 2017. https: //www.wired.co.uk/article/marble-machine-video (accessed 2024-02-07).
[11] E. Sinyor and M. M. Wanderley. Gyrotyre: A dynamic hand-held computer-music controller based on a spinning wheel. In Proceedings of the International Conference on New Interfaces for Musical Expression, pages 42–45, Vancouver, BC, Canada, 2005.
[12] M. Skarha, V. Cusson, C. Frisson, and M. M. Wanderley. Le Bˆaton: A digital musical instrument based on the chaotic triple pendulum. In Proceedings of the International Conference on New Interfaces for Musical Expression, Shanghai, China, June 2021.

## APPENDIX

## A. DETAILS OF THE SIGNAL PROCESS-

## ING ALGORITHMS

We try to outline the mathematical derivations of the algorithms. For details, please refer to the source code.

## A.1 Calibration

### A.1.1 Reference frame

An accelerometer reading is a 3-dimensional vector. When a sufficiently low variation of readings is achieved during calibration, their average vector is normalized and taken as the reference axis u. We find a quaternion q that rotates this vector to the +z unit vector, z

+ =

[

0 0 1]T
. This
is achieved by setting q1 =

[
u × z

+ (1 + u · z

+)

]
and
q = q1 / |q1|.
This quaternion q transforms the reference frame of the accelerometer such that the xy plane corresponds to the local ground, whose normal vector is the z axis. The rotation specified by q is applied to future raw accelerometer readings a˜ and gyroscope readings g˜, assuming that their reference frames are aligned, to yield a carlibrated 6-axis reading: a = qaq˜

−1
, g = qgq˜

−1

### A.1.2 Magnetometer

This task can be formulated as follows: given a set of 3-dimensional vectors {m˜ i}, find an affine transform (Q, o) such that the set of {Qm˜ i + o} best fits onto a unit sphere. We follow the method of [9], employing the ALS estimator in [5] to find a fit (A, c) to the set of equations (m˜ i − c)

TA(m˜ i−c) = 1 and then calculating an inverse transform that converts this ellipsoid back to the unit sphere.
Since the ALS estimator only requires an accumulated matrix Ψ and not the individual values of m˜ i, we are able to carry out the calculation continuously with constant rather than linear memory consumption.

## A.2 Estimation

### A.2.1 Facing

We treat the 2-dimensional orientation angle on the xy plane as the value being estimated. The calibrated magnetometer provides a proportional signal φ, while the calibrated gyroscope provides a derivative signal ˙φ. The input signals are given by φ = − arctan my
mx

and ˙φ = dgy / dt. Here m is the calibrated and aligned magnetometer reading,

m = q (Qm˜ + o) q

−1
,

and g is the calibrated gyroscope reading as is mentioned in section A.1.1.
Following the design in [6], we construct a complementary filter by the transfer equation

φˆ =

1
s

2 + kps + ki

(sφ˙ + (kps + ki)φ) ,

kp =

ω0
QP

, ki = ω

2
0.

This filter yields an estimation ˆφ balancing between the two signals. We fix the pole quality factor as QP = 1 /

√
2 and
empirically tune the corner frequency at ω0 = 24 rad/s ≈ 3.8 Hz.

### A.2.2 Motion

In the extended Kalman filter we formulate the state vector as x =

[

ω A θ B ϕ]T
, charactising an elliptical orbit around the origin — the ideal observation z = [ A cos θ B cos(θ + ϕ)

]T
| is compared against the gyroscope
readings adjusted by the facing estimation,

gˆ

| ′ = rz,θgrˆ

−1
z,θ
where rz,θ =

[
| 0 0 sin θ
2

cos θ
2

]
,

projected onto the xy plane. Varying θ over [0, 2π) traces out an elliptic trajectory of this point and θ is the current phase within the period. ω is the rate of change of phase, dθ / dt, thus the prediction function is
f(x) = [ | ω A θ + ω∆t B ϕ]T

The process noise covariance matrix is set to be a diagonal matrix with the first entry prominently larger than the others, since ω is actively changed by the participant. After the estimations of A, θ, B, ϕ are obtained, we find the corresponding parameter θ at the major axis (which is also the fastest-moving point) by

θ0 =

1
2
arctan | A 2 + B

2
cos 2ϕ
| B² sin 2ϕ

+

1
4

π,

and report the difference θ−θ0 as the final output, so that an output phase of zero aligns with this fastest-moving point.

## B. SOURCE REPOSITORY

All of our design files (printed circuit board assemblies, mechanical models) and source code, as well as extended documentation and demonstrations, are published at https://github.com/ayuusweetfish/Malletwand.

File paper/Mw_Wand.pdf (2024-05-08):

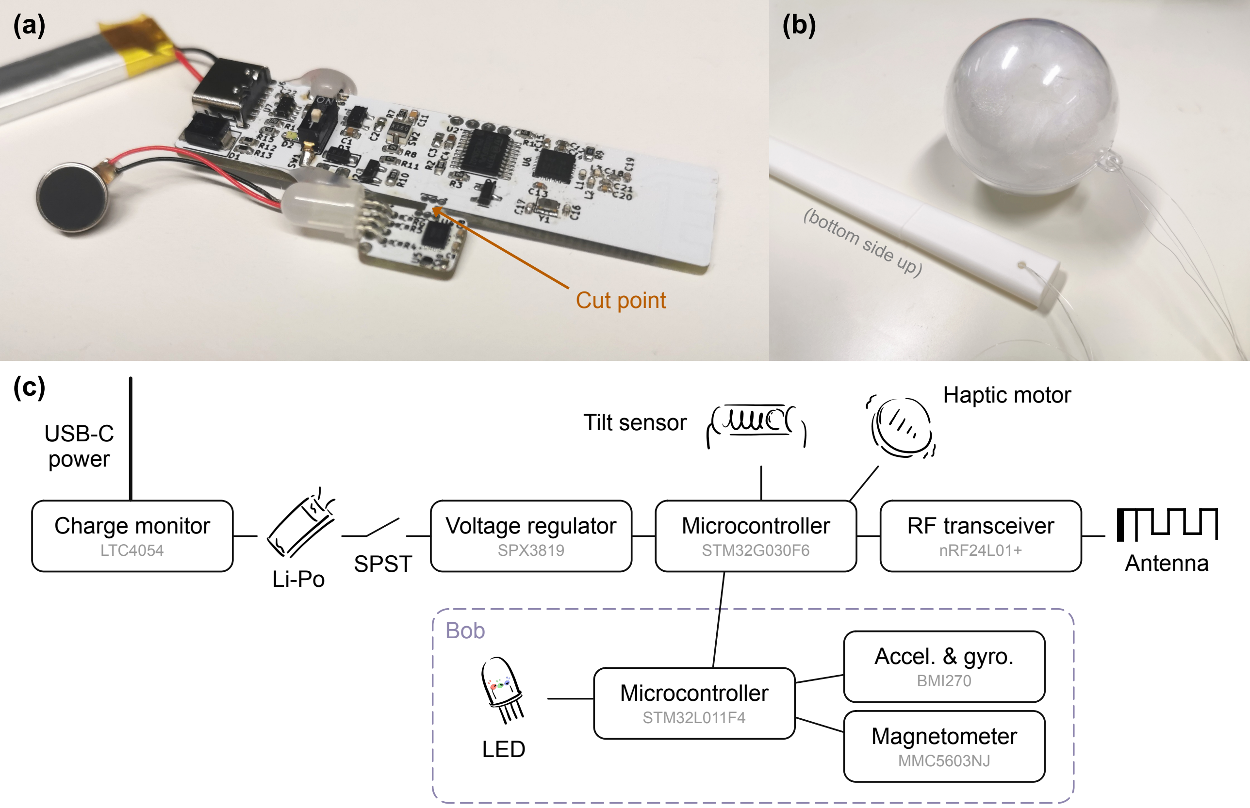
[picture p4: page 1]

Microcontroller
STM32G030F6

Charge monitor
LTC4054

RF transceiver
nRF24L01+

Accel. & gyro.
BMI270

Magnetometer
MMC5603NJ

Voltage regulator
SPX3819 SPST Li-Po

LED

Haptic motor
Tilt sensor

Cut point

(a)

(c)

USB-C
power

Bob

Microcontroller
STM32L011F4

Antenna

(b)

(bot om side up)

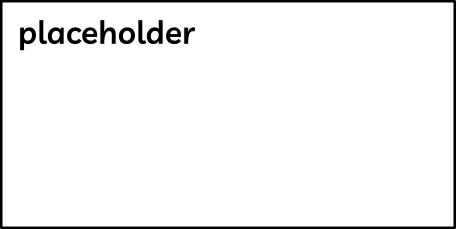
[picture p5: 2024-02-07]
paper/placeholder.png

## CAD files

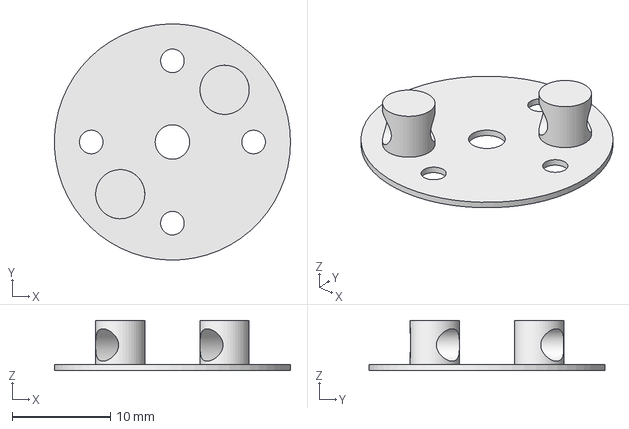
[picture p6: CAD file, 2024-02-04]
mallet/mech/Mallet_Holder.FCStd
24.0 x 24.0 x 5.10 mm

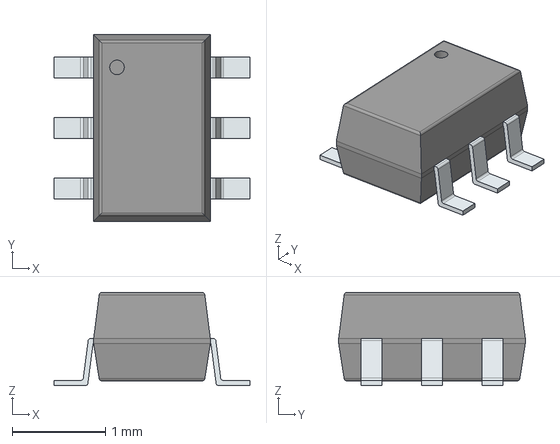
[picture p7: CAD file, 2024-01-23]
mallet_central/hw/lib_models/LTC4311CSC6#TRPBF.stp
2.10 x 2.00 x 1.00 mm
PinsArrayLR

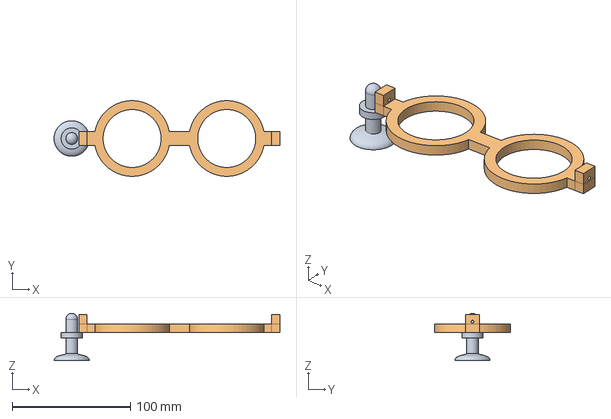
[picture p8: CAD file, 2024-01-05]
testdrive/mech/2x_D7_Holder.FCStd
191.0 x 63.9 x 40.0 mm

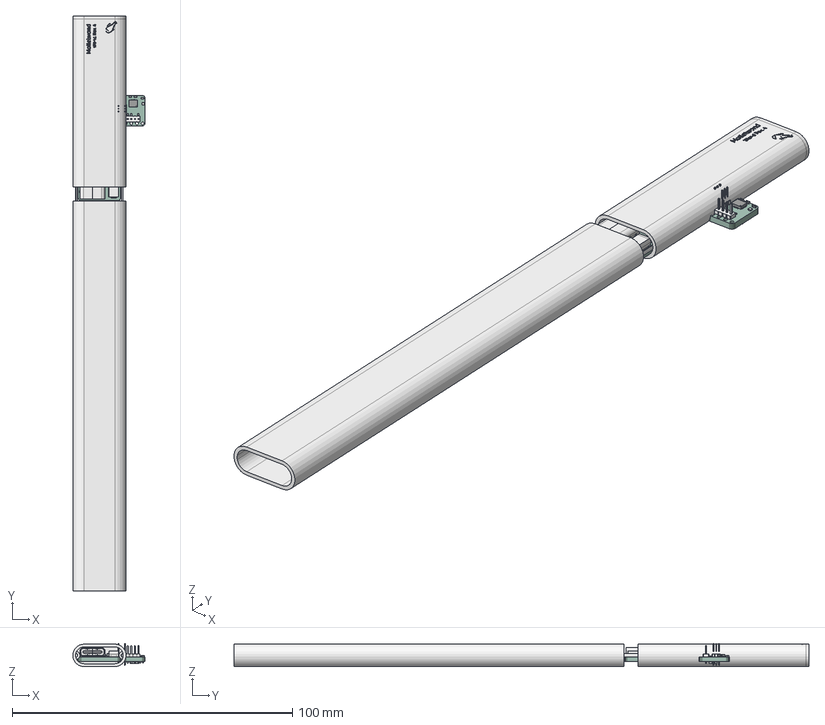
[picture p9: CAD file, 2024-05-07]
wand/mech/Handle.FCStd
25.8 x 205.0 x 8.25 mm
PinHeader_1x03_P100mm_Vertical
C_0603_1608Metric
R_0402_1005Metric
TSSOP_20_44x65mm_P065mm
C_0402_1005Metric
C_0603_1608Metric002
WLP_4_086x086mm_P04mm
C_0402_1005Metric002
R_0402_1005Metric002
PinHeader_1x04_P127mm_Vertical
C_0402_1005Metric004
C_0402_1005Metric006
C_0402_1005Metric008
R_0603_1608Metric
SOT_23_5
R_0603_1608Metric002
R_0603_1608Metric004
R_0603_1608Metric006
C_0402_1005Metric010
C_0402_1005Metric012
R_0603_1608Metric008
C_0402_1005Metric014
C_0402_1005Metric016
C_0402_1005Metric018
D_SOD_123
USB_C_Receptacle_16P_TopMnt_Horizontal_GCT_USB4105-xx-A
USB_C_Receptacle_16P_TopMnt_Horizontal_GCT_USB4105-xx-A001
USB_C_Receptacle_16P_TopMnt_Horizontal_GCT_USB4105-xx-A002
USB_C_Receptacle_16P_TopMnt_Horizontal_GCT_USB4105-xx-A003
USB_C_Receptacle_16P_TopMnt_Horizontal_GCT_USB4105-xx-A004
USB_C_Receptacle_16P_TopMnt_Horizontal_GCT_USB4105-xx-A005
USB_C_Receptacle_16P_TopMnt_Horizontal_GCT_USB4105-xx-A006
USB_C_Receptacle_16P_TopMnt_Horizontal_GCT_USB4105-xx-A007
USB_C_Receptacle_16P_TopMnt_Horizontal_GCT_USB4105-xx-A008
USB_C_Receptacle_16P_TopMnt_Horizontal_GCT_USB4105-xx-A009
USB_C_Receptacle_16P_TopMnt_Horizontal_GCT_USB4105-xx-A010
USB_C_Receptacle_16P_TopMnt_Horizontal_GCT_USB4105-xx-A011
USB_C_Receptacle_16P_TopMnt_Horizontal_GCT_USB4105-xx-A012
USB_C_Receptacle_16P_TopMnt_Horizontal_GCT_USB4105-xx-A013
USB_C_Receptacle_16P_TopMnt_Horizontal_GCT_USB4105-xx-A014
USB_C_Receptacle_16P_TopMnt_Horizontal_GCT_USB4105-xx-A015
USB_C_Receptacle_16P_TopMnt_Horizontal_GCT_USB4105-xx-A016
USB_C_Receptacle_16P_TopMnt_Horizontal_GCT_USB4105-xx-A017
USB_C_Receptacle_16P_TopMnt_Horizontal_GCT_USB4105-xx-A018
USB_C_Receptacle_16P_TopMnt_Horizontal_GCT_USB4105-xx-A019
USB_C_Receptacle_16P_TopMnt_Horizontal_GCT_USB4105-xx-A020
USB_C_Receptacle_16P_TopMnt_Horizontal_GCT_USB4105-xx-A021
USB_C_Receptacle_16P_TopMnt_Horizontal_GCT_USB4105-xx-A022
USB_C_Receptacle_16P_TopMnt_Horizontal_GCT_USB4105-xx-A023
USB_C_Receptacle_16P_TopMnt_Horizontal_GCT_USB4105-xx-A024
USB_C_Receptacle_16P_TopMnt_Horizontal_GCT_USB4105-xx-A025
USB_C_Receptacle_16P_TopMnt_Horizontal_GCT_USB4105-xx-A026
USB_C_Receptacle_16P_TopMnt_Horizontal_GCT_USB4105-xx-A027
USB_C_Receptacle_16P_TopMnt_Horizontal_GCT_USB4105-xx-A028
USB_C_Receptacle_16P_TopMnt_Horizontal_GCT_USB4105-xx-A029
USB_C_Receptacle_16P_TopMnt_Horizontal_GCT_USB4105-xx-A030
USB_C_Receptacle_16P_TopMnt_Horizontal_GCT_USB4105-xx-A031
USB_C_Receptacle_16P_TopMnt_Horizontal_GCT_USB4105-xx-A032
USB_C_Receptacle_16P_TopMnt_Horizontal_GCT_USB4105-xx-A033
USB_C_Receptacle_16P_TopMnt_Horizontal_GCT_USB4105-xx-A034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

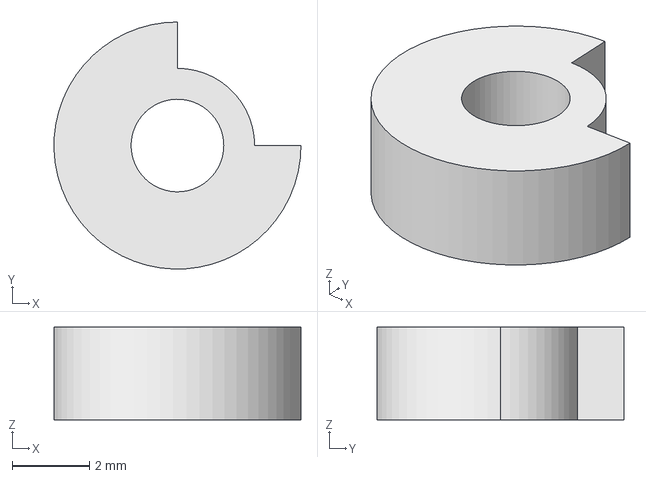
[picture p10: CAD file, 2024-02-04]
mallet/mech/Elev_Ring.FCStd
6.40 x 6.40 x 2.40 mm

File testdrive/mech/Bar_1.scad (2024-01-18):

module bar(w, h, alpha) {
    difference() {
        square([w, h], center = true);
        translate([0, h * (1/2 - alpha), 0])
            circle(r = 5.5/2, $fn = 96);
    }
}

alpha = 0.216;
w = 32;
space = w * 1.25;
rate = 2^(1/12);
translate([space*-1, 0, 0]) bar(w, 200/rate^0, alpha);
translate([space* 0, 0, 0]) bar(w, 200/rate^1, alpha);
translate([space* 1, 0, 0]) bar(w, 200/rate^2, alpha);

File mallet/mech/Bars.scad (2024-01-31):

// Testrun:
// 641.7 Hz, 200 mm
// 719.6 Hz, 200 * 2^(-2/24) mm
// 807.8 Hz, 200 * 2^(-4/24) mm

// Solving k / L^2 = f for k gives
// A = [200^-2; (200*(2^(-1/12)))^-2; (200*(2^(-2/12)))^-2]
// y = [641.7; 719.6; 807.8]
// A \ y = 2.56509629165051e7
// = 641.2740729126275 * 200^2

// At A4 = 442 Hz, Db5 = 442*2^(4/12) = 556.885104053534 Hz
// L = sqrt(k / f) = 200 * sqrt(641.2740729126275 / 556.885104053534)
//   = 214.6194293496366 mm

L0 = 214.6194293496366;

module bar(w, h, drill_pos) {
  echo(h * (0.25 - drill_pos)); // Clearance from the fixation to the node
  difference() {
    square([w, h], center = true);
    translate([0, h * (1/2 - drill_pos), 0])
      circle(r = 4.5/2, $fn = 96);
  }
}

drill_pos = 0.216;
w = 32;
space = w * 1.25;

scale_notes = [
// I  II III  IV #IV   V  #V  VI VII
   0,  2,  4,  5,  6,  7,  8,  9, 11,
  12, 14, 16, 17, 18, 19, 20, 21, 23,
  24, 26, 27
];
for (i = [0 : len(scale_notes) - 1]) {
  translate([space*i, 0, 0]) bar(w, L0 * 2^(-scale_notes[i]/24), drill_pos);
}

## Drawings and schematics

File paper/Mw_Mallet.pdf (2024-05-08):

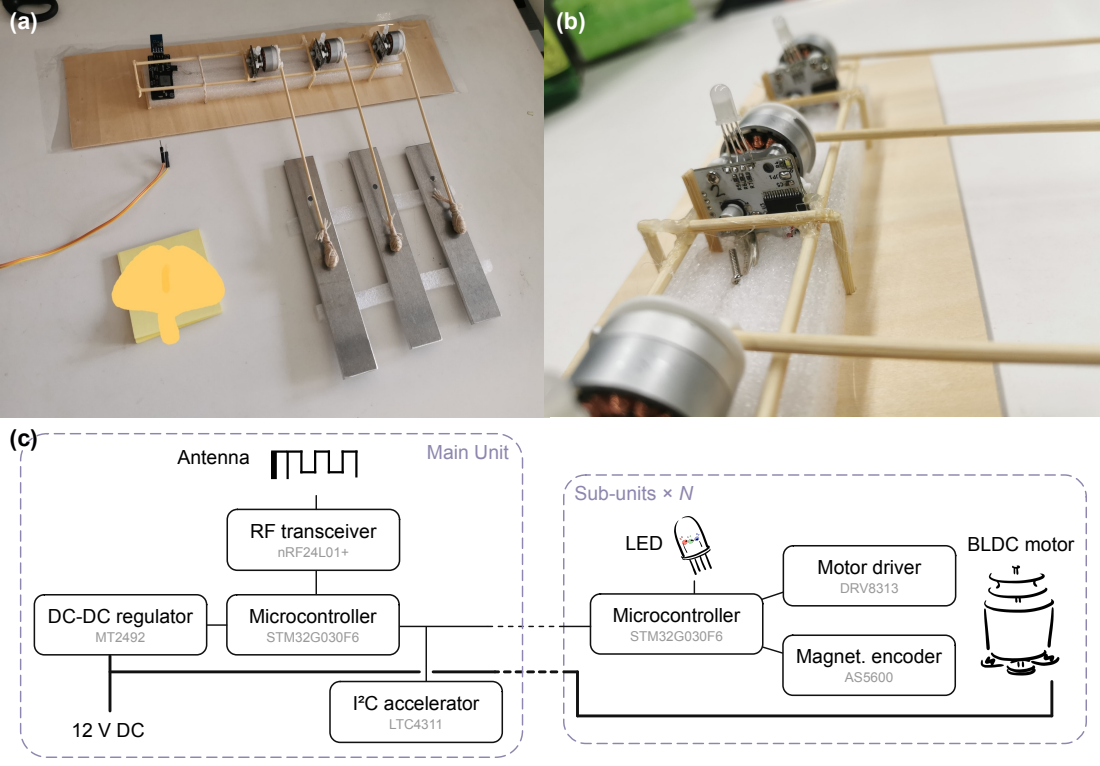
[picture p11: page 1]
Microcontroller; STM32G030F6; RF transceiver; nRF24L01+; I²C accelerator; LTC4311; Antenna; Motor driver; DRV8313; Magnet. encoder; LED; Sub-units × N; BLDC motor; Main Unit (c)

DC-DC regulator

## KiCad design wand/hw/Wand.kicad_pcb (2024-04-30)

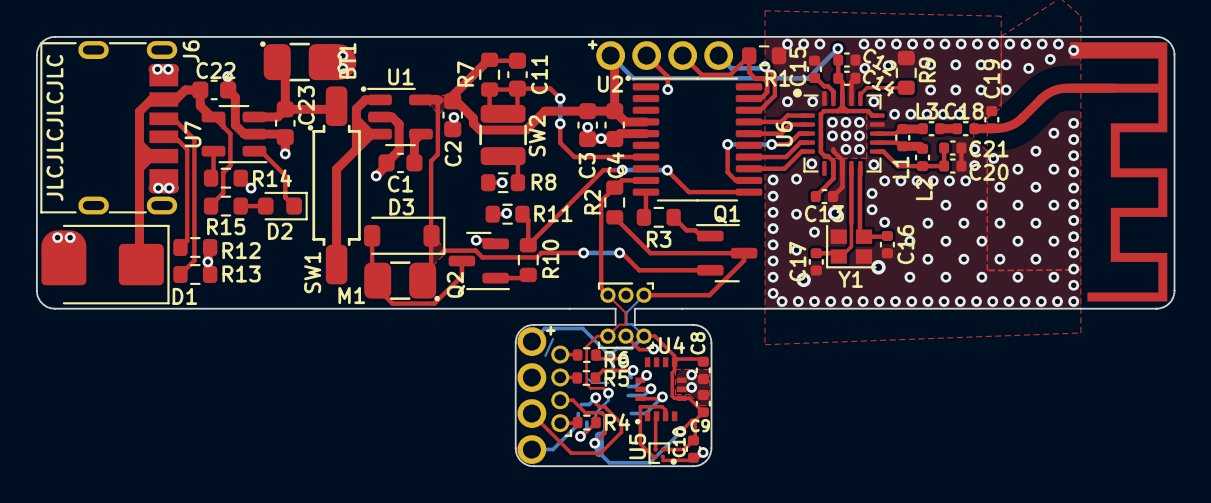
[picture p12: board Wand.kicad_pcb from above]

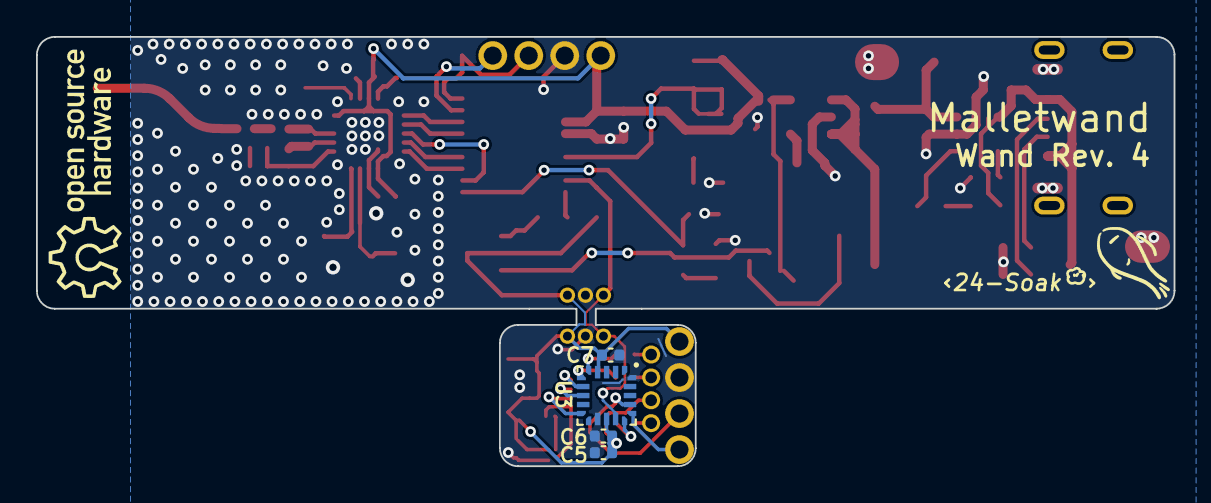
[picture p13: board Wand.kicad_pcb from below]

Board: 2 copper layers, 63.2 x 23.8 mm, 65 parts (4 on the bottom side), 49 nets.

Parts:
AE1: 2.4GHz 50R; ANT_IFA_USB_2.4GHz_50R
BT1: LiPo; Pads_1x02_P2.5
C1: 10n; C_0603_1608Metric
C2, C3, C22: 4.7u; C_0603_1608Metric
C4: 100n; C_0603_1608Metric
C5: 10u; C_0402_1005Metric
C6, C7, C8, C9: 100n; C_0402_1005Metric
C10: 2.2u; C_0402_1005Metric
C11: 1n; C_0603_1608Metric
C12: 4.7u; C_0402_1005Metric
C13, C14: 10n; C_0402_1005Metric
C15: 33n; C_0402_1005Metric
C16, C17: 10p; C_0402_1005Metric
C18: 1.5p; C_0402_1005Metric
C19: 1p; C_0402_1005Metric
C20: 2.2n; C_0402_1005Metric
C21: 4.7p; C_0402_1005Metric
C23: 10u; C_0603_1608Metric
D1: SMBJ5.0A; D_SMB
D2: LED; LED_0603_1608Metric
D3: MBR0530; D_SOD-123
J1, J4: Conn_01x04; TestPoints_1x04_P2.0
J2, J3: Conn_01x03; PinHeader_1x03_P1.00mm_Vertical
J5: Conn_01x04; PinHeader_1x04_P1.27mm_Vertical
J6: USB_C_Receptacle_PowerOnly_6P; USB_C_Receptacle
L1: 8.2n; C_0402_1005Metric
L2: 2.7n; C_0402_1005Metric
L3: 3.9n; C_0402_1005Metric
M1: Vib; Pads_1x02_P2.5
Q1: Si2301; SOT-23
Q2: Si2302; SOT-23
R1: 1.2M; R_0603_1608Metric
R2, R3, R10: 1k; R_0603_1608Metric
R4, R5, R6: 2k TBD; R_0402_1005Metric
R7: 3.3M; R_0603_1608Metric
R8, R11: 100k; R_0603_1608Metric
R9: 22k; R_0603_1608Metric
R12, R13: 5.1k; R_0603_1608Metric
R14: 2k; R_0603_1608Metric
R15: 6.8k; R_0603_1608Metric
SW1: SW_SPST; SPST_1x01_P2.54
SW2: Vib; VibSwitch_JYX-1210-X160
U1: SPX3819M5-L-3-3; SOT-23-5
U2: STM32G030F6Px; TSSOP-20_4.4x6.5mm_P0.65mm
U3: STM32L011F4Ux; ST_UFQFPN-20_3x3mm_P0.5mm
U4: BMI270; QFN50P300X250X87-14N
U5: MMC5603NJ; WLP-4_0.86x0.86mm_P0.4mm
U6: nRF24L01P; QFN-20-P0.5
U7: LTC4054ES5-4.2; TSOT-23-5
Y1: 16MHz; Crystal_SMD_2016-4Pin_2.0x1.6mm

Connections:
BMI_CS: U3.7 (PA4), U4.12 (CSB)
BMI_MOSI: U3.10 (PA7), U4.14 (SDX)
BMI_SCK: U3.8 (PA5), U4.13 (SCX)
BOB_DA: J2.3, J3.3, R2.1, U2.9 (PA2), U3.14 (PA9)
BSWCLK: J4.3, U3.17 (PA14)
BSWDIO: J4.4, U3.16 (PA13)
GND: AE1.2, BT1.2 (-), C1.2, C2.2, C3.2, C4.2, C5.2, C6.2, C7.2, C8.2, C9.2, C10.1, C12.2, C13.2, C14.2, C15.2, C16.2, C17.2, C19.2, C20.2, C21.2, C22.2, C23.2, D1.2 (A2), J1.2, J2.2, J3.2, J4.2, J6.A12 (GND), J6.B12 (GND), Q2.2 (S), R1.2, R8.1, R9.2, R11.1, R12.2, R13.2, R14.2, U1.2 (GND), U2.5 (VSS), U3.12 (VSS), U3.20 (PB9), U4.6 (GNDIO), U4.7 (GND), U5.A1 (VSA), U6.8 (VSS), U6.14 (VSS), U6.17 (VSS), U6.20 (VSS), U7.2 (GND), Y1.2, Y1.4
HSWCLK: J1.3, R1.1, U2.19 (PA14/PA15)
HSWDIO: J1.4, U2.18 (PA13)
LED_B: R6.2, U3.5 (PA0)
LED_G: R5.2, U3.6 (PA1)
LED_R: R4.2, U3.15 (PA10)
MOTOR_G: R10.1, R11.2, U2.11 (PA4)
unnamed: AE1.1, C18.2, C19.1
unnamed: C18.1, L3.2
unnamed: D2.2 (A), R15.2
unnamed: D2.1 (K), U7.1 (~CHRG)
unnamed: D3.2 (A), M1.2 (-), Q2.3 (D)
unnamed: J5.1, R4.1
unnamed: J5.3, R5.1
unnamed: J5.4, R6.1
unnamed: J6.A5 (CC1), R13.1
unnamed: J6.B5 (CC2), R12.1
unnamed: Q1.1 (G), R3.2
unnamed: Q2.1 (G), R10.2
unnamed: R8.2, SW2.1
unnamed: SW1.2 (B), U1.1 (IN), U1.3 (EN)
unnamed: C1.1, U1.4 (BP)
unnamed: U4.3 (ASCX), U5.A2 (SCL)
unnamed: U4.2 (ASDX), U5.B2 (SDA)
unnamed: L1.1, L2.1, U6.12 (ANT1)
unnamed: L1.2, L3.1, U6.13 (ANT2)
unnamed: C15.1, U6.19 (DVDD)
unnamed: R9.1, U6.16 (IREF)
unnamed: C20.1, C21.1, L2.2, U6.11 (VDD_PA)
unnamed: C16.1, U6.10 (XC1), Y1.3
unnamed: C17.1, U6.9 (XC2), Y1.1
unnamed: R14.1, U7.5 (PROG)
SUB_VDD_G: R3.1, U2.10 (PA3)
VBAT: BT1.1 (+), C23.1, SW1.1 (A), U7.3 (BAT)
VBUS: C22.1, D1.1 (A1), J6.A9 (VBUS), J6.B9 (VBUS), R15.1, U7.4 (V_{CC})
VDD: C2.1, C3.1, C4.1, C11.1, C12.1, C13.1, C14.1, D3.1 (K), J1.1, M1.1 (+), Q1.2 (S), R7.2, U1.5 (OUT), U2.4 (VDD), U6.7 (VDD), U6.15 (VDD), U6.18 (VDD)
VDDSUB: C5.1, C6.1, C7.1, C8.1, C9.1, C10.2, J2.1, J3.1, J4.1, J5.2, Q1.3 (D), R2.2, U3.4 (VDDA), U3.13 (VDD), U4.5 (VDDIO), U4.8 (VDD), U5.B1 (VDD)
VIB_TRG: C11.2, R7.1, SW2.2, U2.7 (PA0)
nRF_CE: U2.17 (PA12/PA10), U6.1 (CE)
nRF_CS: U2.16 (PA11/PA9), U6.2 (CSN)
nRF_MISO: U2.13 (PA6), U6.5 (MISO)
nRF_MOSI: U2.14 (PA7), U6.4 (MOSI)
nRF_SCK: U2.12 (PA5), U6.3 (SCK)

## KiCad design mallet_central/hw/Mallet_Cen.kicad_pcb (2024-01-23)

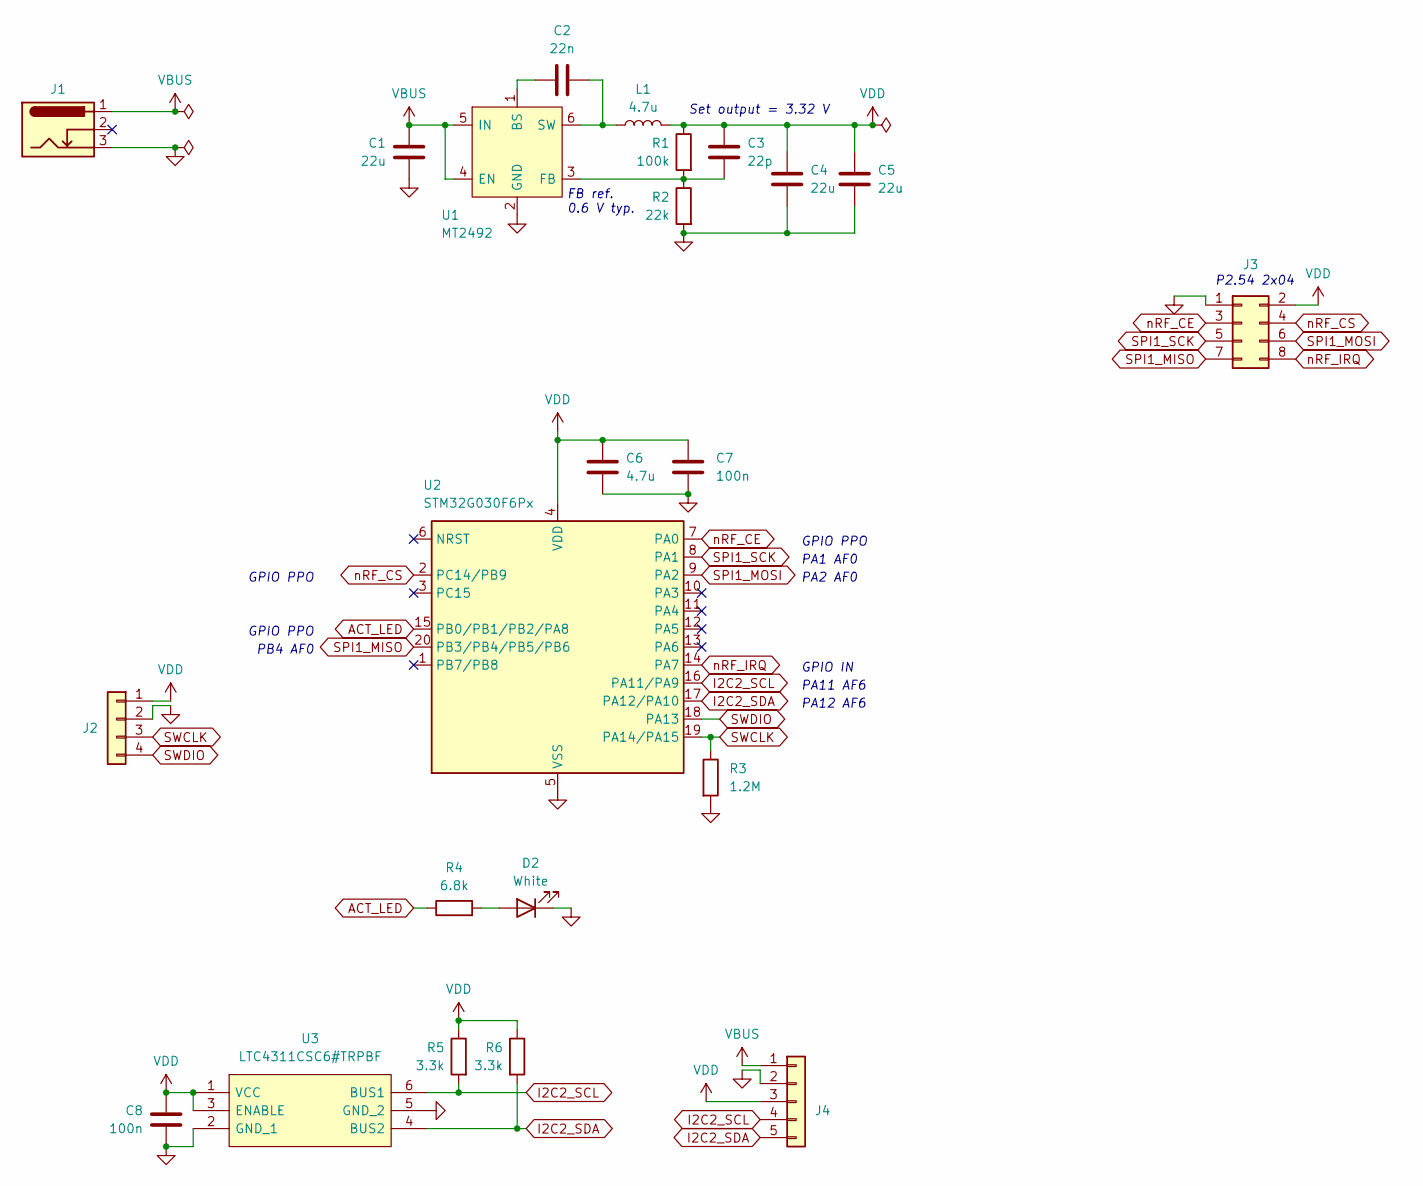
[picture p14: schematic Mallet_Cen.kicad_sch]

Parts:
C1, C4, C5: 22u; C_0603_1608Metric
C2: 22n; C_0603_1608Metric
C3: 22p; C_0603_1608Metric
C6: 4.7u; C_0603_1608Metric
C7, C8: 100n; C_0603_1608Metric
D2: White; LED_0603_1608Metric
J1: Barrel_Jack_Switch_Pin3Ring; BarrelJack_DC022
J2: Conn_01x04; TestPoints_1x04_P2.0
J3: Conn_02x04_Odd_Even; PinSocket_2x04_P2.54mm_Vertical
J4: Conn_01x05; PinHeader_1x05_P2.00mm_Vertical
L1: 4.7u; L_Sunlord_MWSA1004S
R1: 100k; R_0603_1608Metric
R2: 22k; R_0603_1608Metric
R3: 1.2M; R_0603_1608Metric
R4: 6.8k; R_0603_1608Metric
R5, R6: 3.3k; R_0603_1608Metric
U1: MT2492; SOT-23-6; Manufacturer_Part_Number MT2492
U2: STM32G030F6Px; TSSOP-20_4.4x6.5mm_P0.65mm
U3: LTC4311CSC6#TRPBF; SOT65P210X100-6N; Manufacturer_Part_Number LTC4311CSC6#TRPBF; Mouser Part Number 584-LTC4311CSC6TRPBF

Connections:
ACT_LED: R4.1, U2.15 (PB0/PB1/PB2/PA8)
GND: C1.2, C4.2, C5.2, C6.2, C7.2, C8.2, D2.1 (K), J1.3, J2.2, J3.1, J4.2, R2.2, R3.2, U1.2 (GND), U2.5 (VSS), U3.2 (GND_1), U3.5 (GND_2)
I2C2_SCL: J4.4, R5.2, U2.16 (PA11/PA9), U3.6 (BUS1)
I2C2_SDA: J4.5, R6.2, U2.17 (PA12/PA10), U3.4 (BUS2)
unnamed: D2.2 (A), R4.2
unnamed: C2.1, U1.1 (BS)
unnamed: C3.2, R1.2, R2.1, U1.3 (FB)
unnamed: C2.2, L1.1, U1.6 (SW)
SPI1_MISO: J3.7, U2.20 (PB3/PB4/PB5/PB6)
SPI1_MOSI: J3.6, U2.9 (PA2)
SPI1_SCK: J3.5, U2.8 (PA1)
SWCLK: J2.3, R3.1, U2.19 (PA14/PA15)
SWDIO: J2.4, U2.18 (PA13)
VBUS: C1.1, J1.1, J4.1, U1.4 (EN), U1.5 (IN)
VDD: C3.1, C4.1, C5.1, C6.1, C7.1, C8.1, J2.1, J3.2, J4.3, L1.2, R1.1, R5.1, R6.1, U2.4 (VDD), U3.1 (VCC), U3.3 (ENABLE)
nRF_CE: J3.3, U2.7 (PA0)
nRF_CS: J3.4, U2.2 (PC14/PB9)
nRF_IRQ: J3.8, U2.14 (PA7)

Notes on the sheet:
PA1 AF0
GPIO IN
PA11 AF6
PA2 AF0
GPIO PPO
Set output = 3.32 V
P2.54 2x04
PA12 AF6
PB4 AF0
FB ref. 0.6 V typ.

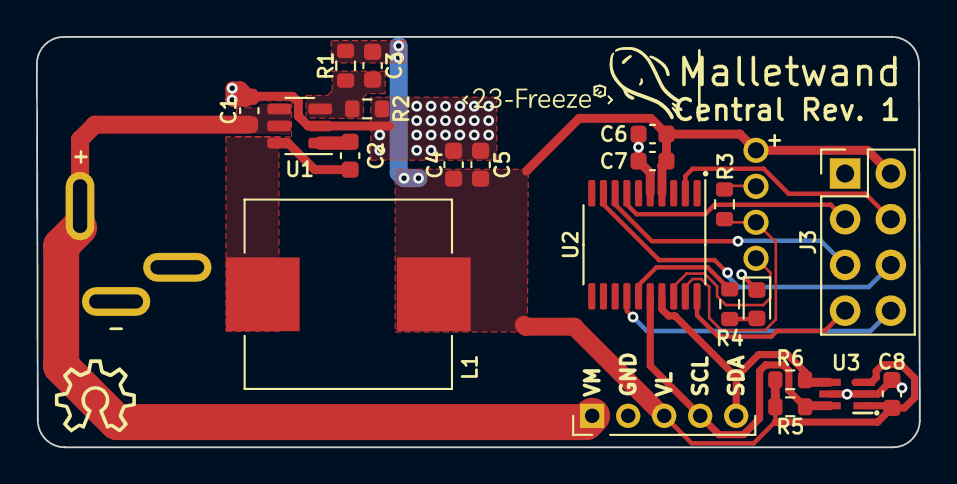
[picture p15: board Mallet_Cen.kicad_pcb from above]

Board: 2 copper layers, 49.0 x 22.8 mm, 23 parts (0 on the bottom side), 18 nets.

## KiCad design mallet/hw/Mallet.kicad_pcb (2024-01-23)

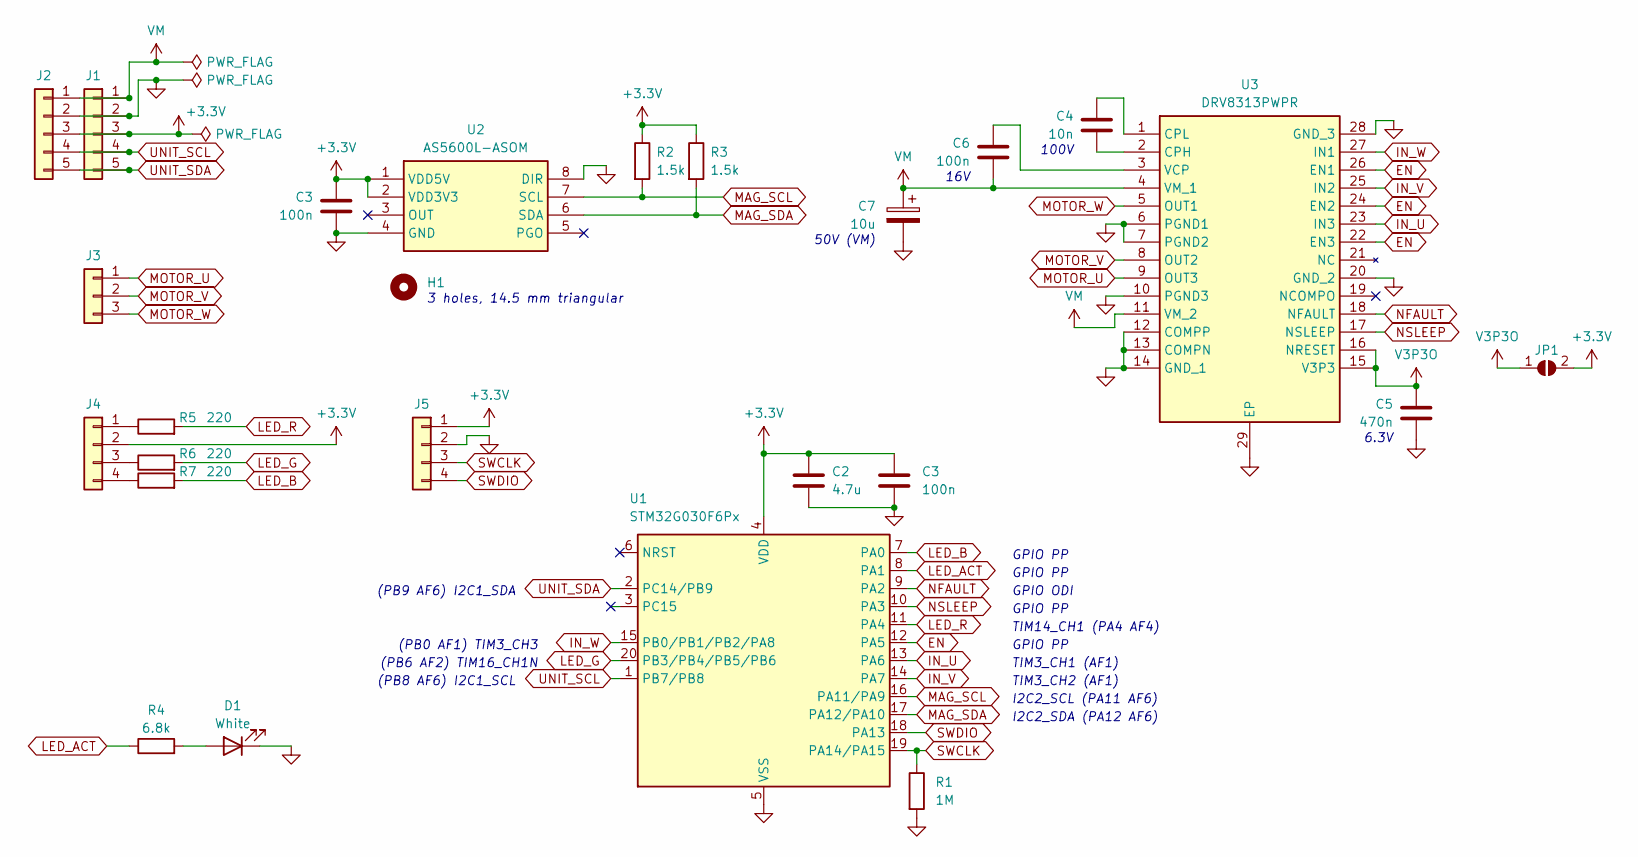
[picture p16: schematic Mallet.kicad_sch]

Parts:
C2: 4.7u; C_0603_1608Metric
C3, C6: 100n; C_0603_1608Metric
C4: 10n; C_0603_1608Metric
C5: 470n; C_0603_1608Metric
C7: 10u; CP_Elec_5x3.9
D1: White; LED_0603_1608Metric
H1: MountingHole; MountingHoles_M3_Tri14.5
J1, J2: Conn_01x05; PinHeader_1x05_P2.00mm_Vertical
J3: Conn_01x03; PinHeader_1x03_P2.00mm_Vertical
J4: Conn_01x04; PinHeader_1x04_P2.00mm_Vertical
J5: Conn_01x04; TestPoints_1x04_P2.0
JP1: SolderJumper_2_Open; SolderJumper-2_P1.3mm_Open_RoundedPad1.0x1.5mm
R1: 1M; R_0603_1608Metric
R2, R3: 1.5k; R_0603_1608Metric
R4: 6.8k; R_0603_1608Metric
R5, R6, R7: 220; R_0603_1608Metric
U1: STM32G030F6Px; TSSOP-20_4.4x6.5mm_P0.65mm
U2: AS5600L-ASOM; SOIC127P600X175-8N; Manufacturer_Part_Number AS5600L-ASOM; Mouser Part Number 985-AS5600L-ASOM
U3: DRV8313PWPR; SOP65P640X120-29N; Manufacturer_Part_Number DRV8313PWPR; Mouser Part Number 595-DRV8313PWPR

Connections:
+3.3V: C2.1, C3.1, J1.3, J2.3, J4.2, J5.1, JP1.2 (B), R2.1, R3.1, U1.4 (VDD), U2.1 (VDD5V), U2.2 (VDD3V3); also elsewhere on the board
EN: U1.12 (PA5), U3.22 (EN3), U3.24 (EN2), U3.26 (EN1)
GND: C2.2, C3.2, C5.2, C7.2, D1.1 (K), J1.2, J2.2, J5.2, R1.2, U1.5 (VSS), U2.4 (GND), U2.8 (DIR), U3.6 (PGND1), U3.7 (PGND2), U3.10 (PGND3), U3.12 (COMPP), U3.13 (COMPN), U3.14 (GND_1), U3.20 (GND_2), U3.28 (GND_3), U3.29 (EP); also elsewhere on the board
IN_U: U1.13 (PA6), U3.23 (IN3)
IN_V: U1.14 (PA7), U3.25 (IN2)
IN_W: U1.15 (PB0/PB1/PB2/PA8), U3.27 (IN1)
LED_ACT: R4.1, U1.8 (PA1)
LED_B: R7.2, U1.7 (PA0)
LED_G: R6.2, U1.20 (PB3/PB4/PB5/PB6)
LED_R: R5.2, U1.11 (PA4)
MAG_SCL: R2.2, U1.16 (PA11/PA9), U2.7 (SCL)
MAG_SDA: R3.2, U1.17 (PA12/PA10), U2.6 (SDA)
MOTOR_U: J3.1, U3.9 (OUT3)
MOTOR_V: J3.2, U3.8 (OUT2)
MOTOR_W: J3.3, U3.5 (OUT1)
NFAULT: U1.9 (PA2), U3.18 (NFAULT)
NSLEEP: U1.10 (PA3), U3.17 (NSLEEP)
unnamed: D1.2 (A), R4.2
unnamed: J4.1, R5.1
unnamed: J4.3, R6.1
unnamed: J4.4, R7.1
unnamed: C4.2, U3.2 (CPH)
unnamed: C4.1, U3.1 (CPL)
unnamed: C6.1, U3.3 (VCP)
SWCLK: J5.3, R1.1, U1.19 (PA14/PA15)
SWDIO: J5.4, U1.18 (PA13)
UNIT_SCL: J1.4, J2.4, U1.1 (PB7/PB8)
UNIT_SDA: J1.5, J2.5, U1.2 (PC14/PB9)
V3P3O: C5.1, JP1.1 (A), U3.15 (V3P3), U3.16 (NRESET)
VM: C6.2, C7.1, J1.1, J2.1, U3.4 (VM_1), U3.11 (VM_2)

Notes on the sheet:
GPIO PP
I2C2_SCL (PA11 AF6)
(PB8 AF6) I2C1_SCL
GPIO ODI
I2C2_SDA (PA12 AF6)
(PB0 AF1) TIM3_CH3
50V (VM)
16V
(PB9 AF6) I2C1_SDA
(PB6 AF2) TIM16_CH1N
100V
TIM3_CH1 (AF1)
TIM3_CH2 (AF1)
TIM14_CH1 (PA4 AF4)
6.3V
3 holes, 14.5 mm triangular

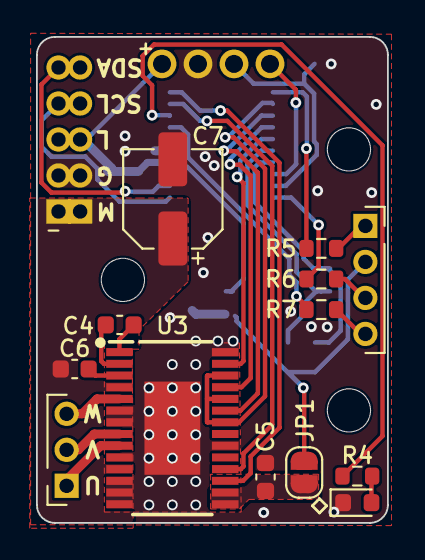
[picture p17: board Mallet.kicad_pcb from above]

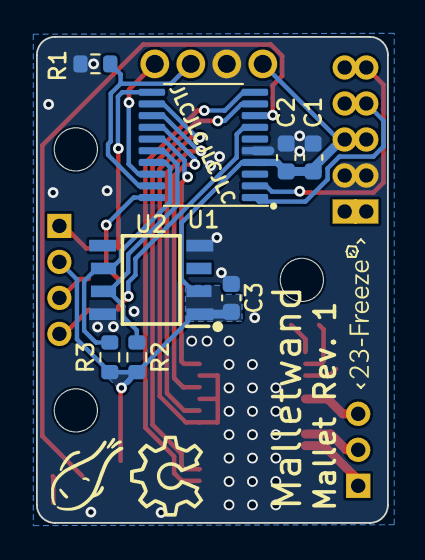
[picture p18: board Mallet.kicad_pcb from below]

Board: 2 copper layers, 19.5 x 27.0 mm, 25 parts (8 on the bottom side), 30 nets.

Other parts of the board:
C1: 4.7u; C_0603_1608Metric

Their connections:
+3.3V: C1.1; also elsewhere on the board
GND: C1.2; also elsewhere on the board

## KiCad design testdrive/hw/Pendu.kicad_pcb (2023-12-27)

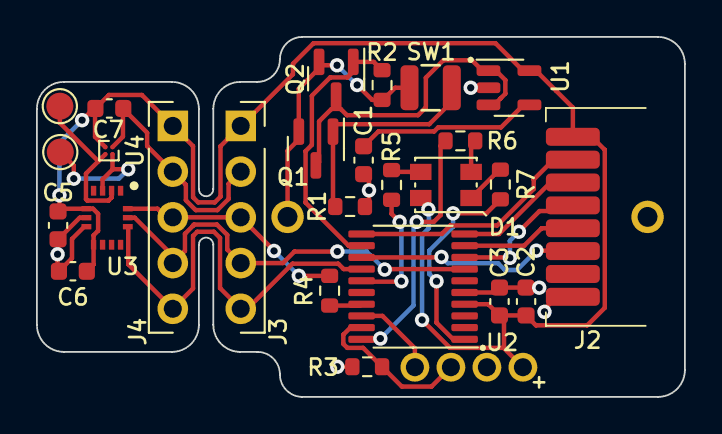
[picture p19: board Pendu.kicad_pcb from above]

Board: 2 copper layers, 36.0 x 20.0 mm, 28 parts (1 on the bottom side), 26 nets.

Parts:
BT1: LIR2016; BatteryHolder_2032_THT_P20
C1: 10n; C_0603_1608Metric
C2: 4.7u; C_0603_1608Metric
C3, C5, C6: 100n; C_0603_1608Metric
C7: 2.2u; C_0603_1608Metric
D1: LED_RABG; LED_Kingbright_AAA3528ESGCT
J1: Conn_01x04; TestPoints_1x04_P2.0
J2: Conn_01x08; SMD_Module_P1.27_1x08
J3, J4: Conn_01x05; PinHeader_1x05_P2.54mm_Vertical
Q1, Q2: Si2301DS; SOT-23
R1, R2, R3: 1.2M; R_0603_1608Metric
R4: 1k; R_0603_1608Metric
R5, R6, R7: TBD; R_0603_1608Metric
SW1: Vib; VibSwitch_JYX-1210-X160
TP1, TP2: TestPoint; TestPoint_Pad_D1.5mm
U1: SPX3819M5-L-3-3; SOT-23-5
U2: STM32G030F6Px; TSSOP-20_4.4x6.5mm_P0.65mm
U3: BMI270; QFN50P300X250X87-14N
U4: MMC5603NJ; WLP-4_0.86x0.86mm_P0.4mm

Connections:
GND: BT1.2 (-), C1.2, C2.2, C3.2, C5.2, C6.2, C7.1, J1.2, J2.8, J3.2, J4.2, R1.2, R3.2, U1.2 (GND), U2.5 (VSS), U3.6 (GNDIO), U3.7 (GND), U4.A1 (VSA)
LED_B: R5.2, U2.15 (PB0/PB1/PB2/PA8)
LED_G: R6.2, U2.20 (PB3/PB4/PB5/PB6)
LED_R: R7.2, U2.1 (PB7/PB8)
unnamed: D1.3 (BK), R5.1
unnamed: D1.4 (GK), R6.1
unnamed: D1.1 (RK), R7.1
unnamed: Q1.3 (D), Q2.3 (D), U1.1 (IN), U1.3 (EN)
unnamed: Q1.1 (G), R1.1, SW1.1
unnamed: C1.1, U1.4 (BP)
unnamed: R4.1, U2.17 (PA12/PA10)
unnamed: TP1.1, U3.3 (ASCX), U4.A2 (SCL)
unnamed: TP2.1, U3.2 (ASDX), U4.B2 (SDA)
PWR_LATCH: Q2.1 (G), R2.2, U2.12 (PA5)
SPI1_CK: J2.4, U2.8 (PA1)
SPI1_CSx: J2.3, U2.10 (PA3)
SPI1_MISO: J2.6, U2.13 (PA6)
SPI1_MOSI: J2.5, U2.9 (PA2)
SPI2_CSx: J3.5, J4.5, U2.14 (PA7), U3.12 (CSB)
SPI2_MOSI: J3.3, J4.3, R4.2, U3.14 (SDX)
SPI2_SCK: J3.4, J4.4, U2.7 (PA0), U3.13 (SCX)
SWCLK: J1.3, R3.1, U2.19 (PA14/PA15)
SWDIO: J1.4, U2.18 (PA13)
VBAT: BT1.1 (+), Q1.2 (S), Q2.2 (S), R2.1, SW1.2
VDD: C2.1, C3.1, C5.1, C6.1, C7.2, D1.2 (A), J1.1, J2.1, J3.1, J4.1, U1.5 (OUT), U2.4 (VDD), U3.5 (VDDIO), U3.8 (VDD), U4.B1 (VDD)
nRF_CE: J2.2, U2.11 (PA4)

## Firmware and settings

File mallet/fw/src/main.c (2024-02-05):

#include <stm32g0xx_hal.h>
#include <math.h>
#include <stdarg.h>
#include <stdbool.h>
#include <stdint.h>
#include <stdio.h>
#include <stdlib.h>

#define KEY_NUM 2

#define LED_IND_ACT_PORT  GPIOA
#define LED_IND_ACT_PIN   GPIO_PIN_1

#define LED_OUT_R_PORT  GPIOA
#define LED_OUT_R_PIN   GPIO_PIN_4
#define LED_OUT_G_PORT  GPIOB
#define LED_OUT_G_PIN   GPIO_PIN_6
#define LED_OUT_B_PORT  GPIOA
#define LED_OUT_B_PIN   GPIO_PIN_0

#define DRV_NFAULT_PORT GPIOA
#define DRV_NFAULT_PIN  GPIO_PIN_2
#define DRV_NSLEEP_PORT GPIOA
#define DRV_NSLEEP_PIN  GPIO_PIN_3
#define DRV_EN_PORT   GPIOA
#define DRV_EN_PIN    GPIO_PIN_5
#define DRV_IN_U_PORT GPIOA
#define DRV_IN_U_PIN  GPIO_PIN_6
#define DRV_IN_V_PORT GPIOA
#define DRV_IN_V_PIN  GPIO_PIN_7
#define DRV_IN_W_PORT GPIOB
#define DRV_IN_W_PIN  GPIO_PIN_0

TIM_HandleTypeDef tim14, tim16, tim17, tim3;
I2C_HandleTypeDef i2c1, i2c2;

static uint8_t swv_buf[256];
static size_t swv_buf_ptr = 0;
__attribute__ ((noinline, used))
void swv_trap_line()
{
  *(volatile char *)swv_buf;
}
static inline void swv_putchar(uint8_t c)
{
  // ITM_SendChar(c);
  if (c == '\n') {
    swv_buf[swv_buf_ptr >= sizeof swv_buf ?
      (sizeof swv_buf - 1) : swv_buf_ptr] = '\0';
    swv_trap_line();
    swv_buf_ptr = 0;
  } else if (++swv_buf_ptr <= sizeof swv_buf) {
    swv_buf[swv_buf_ptr - 1] = c;
  }
}
static void swv_printf(const char *restrict fmt, ...)
{
  char s[256];
  va_list args;
  va_start(args, fmt);
  int r = vsnprintf(s, sizeof s, fmt, args);
  for (int i = 0; i < r && i < sizeof s - 1; i++) swv_putchar(s[i]);
  if (r >= sizeof s) {
    for (int i = 0; i < 3; i++) swv_putchar('.');
    swv_putchar('\n');
  }
}

#define PWM_RESOLUTION 1000
// angle: [0, 36000000)
/*
from math import *
N=720
print(', '.join('%d' % round(1000*(1+0.45*sin(i/N*2*pi))/2) for i in range(N)))
*/
const uint16_t sin_lookup[720] = {
500, 502, 504, 506, 508, 510, 512, 514, 516, 518, 520, 522, 524, 525, 527, 529, 531, 533, 535, 537, 539, 541, 543, 545, 547, 549, 551, 553, 554, 556, 558, 560, 562, 564, 566, 568, 570, 571, 573, 575, 577, 579, 581, 582, 584, 586, 588, 590, 592, 593, 595, 597, 599, 600, 602, 604, 606, 607, 609, 611, 612, 614, 616, 618, 619, 621, 623, 624, 626, 627, 629, 631, 632, 634, 635, 637, 639, 640, 642, 643, 645, 646, 648, 649, 651, 652, 653, 655, 656, 658, 659, 660, 662, 663, 665, 666, 667, 669, 670, 671, 672, 674, 675, 676, 677, 679, 680, 681, 682, 683, 684, 685, 687, 688, 689, 690, 691, 692, 693, 694, 695, 696, 697, 698, 699, 700, 700, 701, 702, 703, 704, 705, 706, 706, 707, 708, 709, 709, 710, 711, 711, 712, 713, 713, 714, 715, 715, 716, 716, 717, 717, 718, 718, 719, 719, 720, 720, 720, 721, 721, 722, 722, 722, 723, 723, 723, 723, 724, 724, 724, 724, 724, 724, 725, 725, 725, 725, 725, 725, 725, 725, 725, 725, 725, 725, 725, 725, 725, 724, 724, 724, 724, 724, 724, 723, 723, 723, 723, 722, 722, 722, 721, 721, 720, 720, 720, 719, 719, 718, 718, 717, 717, 716, 716, 715, 715, 714, 713, 713, 712, 711, 711, 710, 709, 709, 708, 707, 706, 706, 705, 704, 703, 702, 701, 700, 700, 699, 698, 697, 696, 695, 694, 693, 692, 691, 690, 689, 688, 687, 685, 684, 683, 682, 681, 680, 679, 677, 676, 675, 674, 672, 671, 670, 669, 667, 666, 665, 663, 662, 660, 659, 658, 656, 655, 653, 652, 651, 649, 648, 646, 645, 643, 642, 640, 639, 637, 635, 634, 632, 631, 629, 627, 626, 624, 623, 621, 619, 618, 616, 614, 612, 611, 609, 607, 606, 604, 602, 600, 599, 597, 595, 593, 592, 590, 588, 586, 584, 582, 581, 579, 577, 575, 573, 571, 570, 568, 566, 564, 562, 560, 558, 556, 554, 553, 551, 549, 547, 545, 543, 541, 539, 537, 535, 533, 531, 529, 527, 525, 524, 522, 520, 518, 516, 514, 512, 510, 508, 506, 504, 502, 500, 498, 496, 494, 492, 490, 488, 486, 484, 482, 480, 478, 476, 475, 473, 471, 469, 467, 465, 463, 461, 459, 457, 455, 453, 451, 449, 447, 446, 444, 442, 440, 438, 436, 434, 432, 430, 429, 427, 425, 423, 421, 419, 418, 416, 414, 412, 410, 408, 407, 405, 403, 401, 400, 398, 396, 394, 393, 391, 389, 387, 386, 384, 382, 381, 379, 377, 376, 374, 373, 371, 369, 368, 366, 365, 363, 361, 360, 358, 357, 355, 354, 352, 351, 349, 348, 347, 345, 344, 342, 341, 340, 338, 337, 335, 334, 333, 331, 330, 329, 328, 326, 325, 324, 323, 321, 320, 319, 318, 317, 316, 315, 313, 312, 311, 310, 309, 308, 307, 306, 305, 304, 303, 302, 301, 300, 300, 299, 298, 297, 296, 295, 294, 294, 293, 292, 291, 291, 290, 289, 289, 288, 287, 287, 286, 285, 285, 284, 284, 283, 283, 282, 282, 281, 281, 280, 280, 280, 279, 279, 278, 278, 278, 277, 277, 277, 277, 276, 276, 276, 276, 276, 276, 275, 275, 275, 275, 275, 275, 275, 275, 275, 275, 275, 275, 275, 275, 275, 276, 276, 276, 276, 276, 276, 277, 277, 277, 277, 278, 278, 278, 279, 279, 280, 280, 280, 281, 281, 282, 282, 283, 283, 284, 284, 285, 285, 286, 287, 287, 288, 289, 289, 290, 291, 291, 292, 293, 294, 294, 295, 296, 297, 298, 299, 300, 300, 301, 302, 303, 304, 305, 306, 307, 308, 309, 310, 311, 312, 313, 315, 316, 317, 318, 319, 320, 321, 323, 324, 325, 326, 328, 329, 330, 331, 333, 334, 335, 337, 338, 340, 341, 342, 344, 345, 347, 348, 349, 351, 352, 354, 355, 357, 358, 360, 361, 363, 365, 366, 368, 369, 371, 373, 374, 376, 377, 379, 381, 382, 384, 386, 387, 389, 391, 393, 394, 396, 398, 400, 401, 403, 405, 407, 408, 410, 412, 414, 416, 418, 419, 421, 423, 425, 427, 429, 430, 432, 434, 436, 438, 440, 442, 444, 446, 447, 449, 451, 453, 455, 457, 459, 461, 463, 465, 467, 469, 471, 473, 475, 476, 478, 480, 482, 484, 486, 488, 490, 492, 494, 496, 498
};
/*
from math import *
N=720
print(', '.join('%d' % round(1000*(1+0.65*sin(i/N*2*pi))/2) for i in range(N)))
*/
// TODO: Use proper FOC algorithm
const uint16_t sin_lookup_high_power[720] = {
500, 503, 506, 509, 511, 514, 517, 520, 523, 525, 528, 531, 534, 537, 540, 542, 545, 548, 551, 554, 556, 559, 562, 565, 568, 570, 573, 576, 579, 581, 584, 587, 590, 592, 595, 598, 600, 603, 606, 608, 611, 614, 616, 619, 622, 624, 627, 630, 632, 635, 637, 640, 642, 645, 648, 650, 653, 655, 658, 660, 662, 665, 667, 670, 672, 675, 677, 679, 682, 684, 686, 689, 691, 693, 696, 698, 700, 702, 705, 707, 709, 711, 713, 715, 717, 720, 722, 724, 726, 728, 730, 732, 734, 736, 738, 740, 742, 743, 745, 747, 749, 751, 753, 754, 756, 758, 760, 761, 763, 765, 766, 768, 769, 771, 773, 774, 776, 777, 779, 780, 781, 783, 784, 786, 787, 788, 790, 791, 792, 793, 795, 796, 797, 798, 799, 800, 801, 802, 803, 804, 805, 806, 807, 808, 809, 810, 811, 812, 812, 813, 814, 815, 815, 816, 817, 817, 818, 818, 819, 820, 820, 821, 821, 821, 822, 822, 823, 823, 823, 824, 824, 824, 824, 824, 825, 825, 825, 825, 825, 825, 825, 825, 825, 825, 825, 825, 825, 824, 824, 824, 824, 824, 823, 823, 823, 822, 822, 821, 821, 821, 820, 820, 819, 818, 818, 817, 817, 816, 815, 815, 814, 813, 812, 812, 811, 810, 809, 808, 807, 806, 805, 804, 803, 802, 801, 800, 799, 798, 797, 796, 795, 793, 792, 791, 790, 788, 787, 786, 784, 783, 781, 780, 779, 777, 776, 774, 773, 771, 769, 768, 766, 765, 763, 761, 760, 758, 756, 754, 753, 751, 749, 747, 745, 743, 742, 740, 738, 736, 734, 732, 730, 728, 726, 724, 722, 720, 717, 715, 713, 711, 709, 707, 705, 702, 700, 698, 696, 693, 691, 689, 686, 684, 682, 679, 677, 675, 672, 670, 667, 665, 662, 660, 658, 655, 653, 650, 648, 645, 642, 640, 637, 635, 632, 630, 627, 624, 622, 619, 616, 614, 611, 608, 606, 603, 600, 598, 595, 592, 590, 587, 584, 581, 579, 576, 573, 570, 568, 565, 562, 559, 556, 554, 551, 548, 545, 542, 540, 537, 534, 531, 528, 525, 523, 520, 517, 514, 511, 509, 506, 503, 500, 497, 494, 491, 489, 486, 483, 480, 477, 475, 472, 469, 466, 463, 460, 458, 455, 452, 449, 446, 444, 441, 438, 435, 432, 430, 427, 424, 421, 419, 416, 413, 410, 408, 405, 402, 400, 397, 394, 392, 389, 386, 384, 381, 378, 376, 373, 370, 368, 365, 363, 360, 358, 355, 352, 350, 347, 345, 342, 340, 337, 335, 333, 330, 328, 325, 323, 321, 318, 316, 314, 311, 309, 307, 304, 302, 300, 298, 295, 293, 291, 289, 287, 285, 283, 280, 278, 276, 274, 272, 270, 268, 266, 264, 262, 260, 258, 257, 255, 253, 251, 249, 247, 246, 244, 242, 240, 239, 237, 235, 234, 232, 231, 229, 227, 226, 224, 223, 221, 220, 219, 217, 216, 214, 213, 212, 210, 209, 208, 207, 205, 204, 203, 202, 201, 200, 199, 198, 197, 196, 195, 194, 193, 192, 191, 190, 189, 188, 188, 187, 186, 185, 185, 184, 183, 183, 182, 182, 181, 180, 180, 179, 179, 179, 178, 178, 177, 177, 177, 176, 176, 176, 176, 176, 175, 175, 175, 175, 175, 175, 175, 175, 175, 175, 175, 175, 175, 176, 176, 176, 176, 176, 177, 177, 177, 178, 178, 179, 179, 179, 180, 180, 181, 182, 182, 183, 183, 184, 185, 185, 186, 187, 188, 188, 189, 190, 191, 192, 193, 194, 195, 196, 197, 198, 199, 200, 201, 202, 203, 204, 205, 207, 208, 209, 210, 212, 213, 214, 216, 217, 219, 220, 221, 223, 224, 226, 227, 229, 231, 232, 234, 235, 237, 239, 240, 242, 244, 246, 247, 249, 251, 253, 255, 257, 258, 260, 262, 264, 266, 268, 270, 272, 274, 276, 278, 280, 283, 285, 287, 289, 291, 293, 295, 298, 300, 302, 304, 307, 309, 311, 314, 316, 318, 321, 323, 325, 328, 330, 333, 335, 337, 340, 342, 345, 347, 350, 352, 355, 358, 360, 363, 365, 368, 370, 373, 376, 378, 381, 384, 386, 389, 392, 394, 397, 400, 402, 405, 408, 410, 413, 416, 419, 421, 424, 427, 430, 432, 435, 438, 441, 444, 446, 449, 452, 455, 458, 460, 463, 466, 469, 472, 475, 477, 480, 483, 486, 489, 491, 494, 497
};
/*
from math import *
N=720
print(', '.join('%d' % round(1000*(1+0.15*sin(i/N*2*pi))/2) for i in range(N)))
*/
// TODO: Automatically calibrate this
const uint16_t sin_lookup_low_power[720] = {
500, 501, 501, 502, 503, 503, 504, 505, 505, 506, 507, 507, 508, 508, 509, 510, 510, 511, 512, 512, 513, 514, 514, 515, 516, 516, 517, 518, 518, 519, 519, 520, 521, 521, 522, 523, 523, 524, 524, 525, 526, 526, 527, 527, 528, 529, 529, 530, 531, 531, 532, 532, 533, 533, 534, 535, 535, 536, 536, 537, 538, 538, 539, 539, 540, 540, 541, 541, 542, 542, 543, 544, 544, 545, 545, 546, 546, 547, 547, 548, 548, 549, 549, 550, 550, 551, 551, 552, 552, 553, 553, 553, 554, 554, 555, 555, 556, 556, 557, 557, 557, 558, 558, 559, 559, 560, 560, 560, 561, 561, 561, 562, 562, 563, 563, 563, 564, 564, 564, 565, 565, 565, 566, 566, 566, 567, 567, 567, 567, 568, 568, 568, 569, 569, 569, 569, 570, 570, 570, 570, 570, 571, 571, 571, 571, 572, 572, 572, 572, 572, 572, 573, 573, 573, 573, 573, 573, 573, 574, 574, 574, 574, 574, 574, 574, 574, 574, 575, 575, 575, 575, 575, 575, 575, 575, 575, 575, 575, 575, 575, 575, 575, 575, 575, 575, 575, 575, 575, 575, 575, 575, 575, 575, 575, 574, 574, 574, 574, 574, 574, 574, 574, 574, 573, 573, 573, 573, 573, 573, 573, 572, 572, 572, 572, 572, 572, 571, 571, 571, 571, 570, 570, 570, 570, 570, 569, 569, 569, 569, 568, 568, 568, 567, 567, 567, 567, 566, 566, 566, 565, 565, 565, 564, 564, 564, 563, 563, 563, 562, 562, 561, 561, 561, 560, 560, 560, 559, 559, 558, 558, 557, 557, 557, 556, 556, 555, 555, 554, 554, 553, 553, 553, 552, 552, 551, 551, 550, 550, 549, 549, 548, 548, 547, 547, 546, 546, 545, 545, 544, 544, 543, 542, 542, 541, 541, 540, 540, 539, 539, 538, 538, 537, 536, 536, 535, 535, 534, 533, 533, 532, 532, 531, 531, 530, 529, 529, 528, 527, 527, 526, 526, 525, 524, 524, 523, 523, 522, 521, 521, 520, 519, 519, 518, 518, 517, 516, 516, 515, 514, 514, 513, 512, 512, 511, 510, 510, 509, 508, 508, 507, 507, 506, 505, 505, 504, 503, 503, 502, 501, 501, 500, 499, 499, 498, 497, 497, 496, 495, 495, 494, 493, 493, 492, 492, 491, 490, 490, 489, 488, 488, 487, 486, 486, 485, 484, 484, 483, 482, 482, 481, 481, 480, 479, 479, 478, 477, 477, 476, 476, 475, 474, 474, 473, 473, 472, 471, 471, 470, 469, 469, 468, 468, 467, 467, 466, 465, 465, 464, 464, 463, 462, 462, 461, 461, 460, 460, 459, 459, 458, 458, 457, 456, 456, 455, 455, 454, 454, 453, 453, 452, 452, 451, 451, 450, 450, 449, 449, 448, 448, 447, 447, 447, 446, 446, 445, 445, 444, 444, 443, 443, 443, 442, 442, 441, 441, 440, 440, 440, 439, 439, 439, 438, 438, 437, 437, 437, 436, 436, 436, 435, 435, 435, 434, 434, 434, 433, 433, 433, 433, 432, 432, 432, 431, 431, 431, 431, 430, 430, 430, 430, 430, 429, 429, 429, 429, 428, 428, 428, 428, 428, 428, 427, 427, 427, 427, 427, 427, 427, 426, 426, 426, 426, 426, 426, 426, 426, 426, 425, 425, 425, 425, 425, 425, 425, 425, 425, 425, 425, 425, 425, 425, 425, 425, 425, 425, 425, 425, 425, 425, 425, 425, 425, 425, 425, 426, 426, 426, 426, 426, 426, 426, 426, 426, 427, 427, 427, 427, 427, 427, 427, 428, 428, 428, 428, 428, 428, 429, 429, 429, 429, 430, 430, 430, 430, 430, 431, 431, 431, 431, 432, 432, 432, 433, 433, 433, 433, 434, 434, 434, 435, 435, 435, 436, 436, 436, 437, 437, 437, 438, 438, 439, 439, 439, 440, 440, 440, 441, 441, 442, 442, 443, 443, 443, 444, 444, 445, 445, 446, 446, 447, 447, 447, 448, 448, 449, 449, 450, 450, 451, 451, 452, 452, 453, 453, 454, 454, 455, 455, 456, 456, 457, 458, 458, 459, 459, 460, 460, 461, 461, 462, 462, 463, 464, 464, 465, 465, 466, 467, 467, 468, 468, 469, 469, 470, 471, 471, 472, 473, 473, 474, 474, 475, 476, 476, 477, 477, 478, 479, 479, 480, 481, 481, 482, 482, 483, 484, 484, 485, 486, 486, 487, 488, 488, 489, 490, 490, 491, 492, 492, 493, 493, 494, 495, 495, 496, 497, 497, 498, 499, 499
};

// Increasing values correspond to clockwise rotation
static inline void drive_motor(uint32_t angle)
{
  TIM3->CCR1 = sin_lookup[(angle / 50000 +   0) % 720];
  TIM3->CCR2 = sin_lookup[(angle / 50000 + 240) % 720];
  TIM3->CCR3 = sin_lookup[(angle / 50000 + 480) % 720];
}

static inline void drive_motor_high_power(uint32_t angle)
{
  TIM3->CCR1 = sin_lookup_high_power[(angle / 50000 +   0) % 720];
  TIM3->CCR2 = sin_lookup_high_power[(angle / 50000 + 240) % 720];
  TIM3->CCR3 = sin_lookup_high_power[(angle / 50000 + 480) % 720];
}

static inline void drive_motor_low_power(uint32_t angle)
{
  TIM3->CCR1 = sin_lookup_low_power[(angle / 50000 +   0) % 720];
  TIM3->CCR2 = sin_lookup_low_power[(angle / 50000 + 240) % 720];
  TIM3->CCR3 = sin_lookup_low_power[(angle / 50000 + 480) % 720];
}

bool slow_blink_ind_led = false;

int main()
{
  HAL_Init();

  // ======== GPIO ========
  __HAL_RCC_GPIOA_CLK_ENABLE();
  __HAL_RCC_GPIOB_CLK_ENABLE();
  __HAL_RCC_GPIOC_CLK_ENABLE();
  GPIO_InitTypeDef gpio_init;

  gpio_init.Pin = LED_IND_ACT_PIN;
  gpio_init.Mode = GPIO_MODE_OUTPUT_PP;
  gpio_init.Pull = GPIO_PULLDOWN;
  gpio_init.Speed = GPIO_SPEED_FREQ_LOW;
  HAL_GPIO_Init(LED_IND_ACT_PORT, &gpio_init);
  HAL_GPIO_WritePin(LED_IND_ACT_PORT, LED_IND_ACT_PIN, GPIO_PIN_SET);

  // SWD (PA13, PA14)
  gpio_init.Pin = GPIO_PIN_13 | GPIO_PIN_14;
  gpio_init.Mode = GPIO_MODE_AF_PP; // Pass over control to AF peripheral
  gpio_init.Alternate = GPIO_AF0_SWJ;
  gpio_init.Pull = GPIO_PULLUP;
  gpio_init.Speed = GPIO_SPEED_FREQ_HIGH;
  HAL_GPIO_Init(GPIOA, &gpio_init);

  // ======== Clocks ========
  RCC_OscInitTypeDef osc_init = { 0 };
  osc_init.OscillatorType = RCC_OSCILLATORTYPE_HSI;
  osc_init.HSIState = RCC_HSI_ON;
  /* static const int HSI_TRIM[3] = {
    66, 64, 64
  };
  osc_init.HSICalibrationValue = HSI_TRIM[KEY_NUM - 1]; */
  osc_init.PLL.PLLState = RCC_PLL_ON;
  osc_init.PLL.PLLSource = RCC_PLLSOURCE_HSI;
  osc_init.PLL.PLLM = RCC_PLLM_DIV2;
  osc_init.PLL.PLLN = 8;
  osc_init.PLL.PLLP = RCC_PLLP_DIV2;
  osc_init.PLL.PLLR = RCC_PLLR_DIV2;
  HAL_RCC_OscConfig(&osc_init);

  RCC_ClkInitTypeDef clk_init = { 0 };
  clk_init.ClockType =
    RCC_CLOCKTYPE_SYSCLK |
    RCC_CLOCKTYPE_HCLK |
    RCC_CLOCKTYPE_PCLK1;
  clk_init.SYSCLKSource = RCC_SYSCLKSOURCE_PLLCLK;
  clk_init.AHBCLKDivider = RCC_SYSCLK_DIV1;
  clk_init.APB1CLKDivider = RCC_HCLK_DIV1;
  HAL_RCC_ClockConfig(&clk_init, FLASH_LATENCY_2);

  HAL_NVIC_SetPriority(SysTick_IRQn, 0, 0);

  // ======== Timer ========
  // APB1 = 64 MHz
  // period = 4 kHz = 16000 cycles

  // LED Red, TIM14
  gpio_init.Pin = LED_OUT_R_PIN;
  gpio_init.Mode = GPIO_MODE_AF_PP;
  gpio_init.Alternate = GPIO_AF4_TIM14;
  gpio_init.Pull = GPIO_NOPULL;
  gpio_init.Speed = GPIO_SPEED_FREQ_HIGH;
  HAL_GPIO_Init(LED_OUT_R_PORT, &gpio_init);
  __HAL_RCC_TIM14_CLK_ENABLE();
  tim14 = (TIM_HandleTypeDef){
    .Instance = TIM14,
    .Init = {
      .Prescaler = 1 - 1,
      .CounterMode = TIM_COUNTERMODE_UP,
      .Period = 16000 - 1,
      .ClockDivision = TIM_CLOCKDIVISION_DIV1,
      .RepetitionCounter = 0,
    },
  };
  HAL_TIM_PWM_Init(&tim14);
  TIM_OC_InitTypeDef tim14_ch1_oc_init = {
    .OCMode = TIM_OCMODE_PWM2,
    .Pulse = 0, // to be filled
    .OCPolarity = TIM_OCPOLARITY_HIGH,
  };
  HAL_TIM_PWM_ConfigChannel(&tim14, &tim14_ch1_oc_init, TIM_CHANNEL_1);
  HAL_TIM_PWM_Start(&tim14, TIM_CHANNEL_1);

  // LED Green, TIM16
  gpio_init.Pin = LED_OUT_G_PIN;
  gpio_init.Mode = GPIO_MODE_AF_PP;
  gpio_init.Alternate = GPIO_AF2_TIM16;
  gpio_init.Pull = GPIO_NOPULL;
  gpio_init.Speed = GPIO_SPEED_FREQ_HIGH;
  HAL_GPIO_Init(LED_OUT_G_PORT, &gpio_init);
  __HAL_RCC_TIM16_CLK_ENABLE();
  tim16 = (TIM_HandleTypeDef){
    .Instance = TIM16,
    .Init = {
      .Prescaler = 1 - 1,
      .CounterMode = TIM_COUNTERMODE_UP,
      .Period = 16000 - 1,
      .ClockDivision = TIM_CLOCKDIVISION_DIV1,
      .RepetitionCounter = 0,
    },
  };
  HAL_TIM_PWM_Init(&tim16);
  TIM_OC_InitTypeDef tim16_ch1_oc_init = {
    .OCMode = TIM_OCMODE_PWM2,
    .Pulse = 0, // to be filled
    .OCNPolarity = TIM_OCNPOLARITY_HIGH,  // Output is TIM16_CH1N
  };
  HAL_TIM_PWM_ConfigChannel(&tim16, &tim16_ch1_oc_init, TIM_CHANNEL_1);
  HAL_TIMEx_PWMN_Start(&tim16, TIM_CHANNEL_1);

  // LED Blue, TIM17
  gpio_init.Pin = LED_OUT_B_PIN;
  gpio_init.Mode = GPIO_MODE_OUTPUT_PP;
  gpio_init.Alternate = GPIO_AF2_TIM17;
  gpio_init.Pull = GPIO_NOPULL;
  gpio_init.Speed = GPIO_SPEED_FREQ_HIGH;
  HAL_GPIO_Init(LED_OUT_B_PORT, &gpio_init);
  HAL_GPIO_WritePin(LED_OUT_B_PORT, LED_OUT_B_PIN, 1);
  __HAL_RCC_TIM17_CLK_ENABLE();
  tim17 = (TIM_HandleTypeDef){
    .Instance = TIM17,
    .Init = {
      .Prescaler = 1 - 1,
      .CounterMode = TIM_COUNTERMODE_UP,
      .Period = 16000 - 1,
      .ClockDivision = TIM_CLOCKDIVISION_DIV1,
      .RepetitionCounter = 0,
    },
  };
  TIM17->CCR1 = 0;
  HAL_TIM_OC_Init(&tim17);
  HAL_TIM_OC_Start_IT(&tim17, TIM_CHANNEL_1);
  HAL_TIM_Base_Start_IT(&tim17);
  HAL_NVIC_SetPriority(TIM17_IRQn, 1, 0);
  HAL_NVIC_EnableIRQ(TIM17_IRQn);

  // Driver PWMs, TIM3
  gpio_init.Mode = GPIO_MODE_AF_PP;
  gpio_init.Pull = GPIO_NOPULL;
  gpio_init.Speed = GPIO_SPEED_FREQ_HIGH;

  gpio_init.Pin = DRV_IN_U_PIN;
  gpio_init.Alternate = GPIO_AF1_TIM3;
  HAL_GPIO_Init(DRV_IN_U_PORT, &gpio_init);
  gpio_init.Pin = DRV_IN_V_PIN;
  gpio_init.Alternate = GPIO_AF1_TIM3;
  HAL_GPIO_Init(DRV_IN_V_PORT, &gpio_init);
  gpio_init.Pin = DRV_IN_W_PIN;
  gpio_init.Alternate = GPIO_AF1_TIM3;
  HAL_GPIO_Init(DRV_IN_W_PORT, &gpio_init);

  // Timer TIM3
  // APB1 = 64 MHz
  // Period = 64 MHz / 1000 = 64 kHz
  __HAL_RCC_TIM3_CLK_ENABLE();
  tim3 = (TIM_HandleTypeDef){
    .Instance = TIM3,
    .Init = {
      .Prescaler = 1 - 1,
      .CounterMode = TIM_COUNTERMODE_UP,
      // .CounterMode = TIM_COUNTERMODE_CENTERALIGNED1,
      .Period = PWM_RESOLUTION - 1,
      .ClockDivision = TIM_CLOCKDIVISION_DIV1,
      .RepetitionCounter = 0,
    },
  };
  HAL_TIM_PWM_Init(&tim3);
  TIM_OC_InitTypeDef tim3_ch1_oc_init = {
    .OCMode = TIM_OCMODE_PWM2,
    .Pulse = 0, // to be filled
    .OCPolarity = TIM_OCPOLARITY_HIGH,
  };
  HAL_TIM_PWM_ConfigChannel(&tim3, &tim3_ch1_oc_init, TIM_CHANNEL_1);
  HAL_TIM_PWM_Start(&tim3, TIM_CHANNEL_1);
  HAL_TIM_PWM_ConfigChannel(&tim3, &tim3_ch1_oc_init, TIM_CHANNEL_2);
  HAL_TIM_PWM_Start(&tim3, TIM_CHANNEL_2);
  HAL_TIM_PWM_ConfigChannel(&tim3, &tim3_ch1_oc_init, TIM_CHANNEL_3);
  HAL_TIM_PWM_Start(&tim3, TIM_CHANNEL_3);

  // Driver nFAULT, nSLEEP, and EN pins
  gpio_init.Pin = DRV_NFAULT_PIN;
  gpio_init.Mode = GPIO_MODE_INPUT;
  gpio_init.Pull = GPIO_PULLUP;
  gpio_init.Speed = GPIO_SPEED_FREQ_HIGH;
  HAL_GPIO_Init(DRV_NFAULT_PORT, &gpio_init);

  gpio_init.Pin = DRV_NSLEEP_PIN;
  gpio_init.Mode = GPIO_MODE_OUTPUT_PP;
  gpio_init.Pull = GPIO_NOPULL;
  gpio_init.Speed = GPIO_SPEED_FREQ_HIGH;
  HAL_GPIO_Init(DRV_NSLEEP_PORT, &gpio_init);
  HAL_GPIO_WritePin(DRV_NSLEEP_PORT, DRV_NSLEEP_PIN, 1);

  gpio_init.Pin = DRV_EN_PIN;
  gpio_init.Mode = GPIO_MODE_OUTPUT_PP;
  gpio_init.Pull = GPIO_NOPULL;
  gpio_init.Speed = GPIO_SPEED_FREQ_HIGH;
  HAL_GPIO_Init(DRV_EN_PORT, &gpio_init);
  HAL_GPIO_WritePin(DRV_EN_PORT, DRV_EN_PIN, 1);

  // ======== I2C 1 (unit interface) ========
  gpio_init.Pin = GPIO_PIN_8 | GPIO_PIN_9;
  gpio_init.Mode = GPIO_MODE_AF_PP;
  gpio_init.Alternate = GPIO_AF6_I2C1;
  gpio_init.Pull = GPIO_NOPULL;
  gpio_init.Speed = GPIO_SPEED_FREQ_HIGH;
  HAL_GPIO_Init(GPIOB, &gpio_init);

  __HAL_RCC_I2C1_CLK_ENABLE();
  HAL_I2CEx_EnableFastModePlus(I2C_FASTMODEPLUS_I2C1);
  i2c1 = (I2C_HandleTypeDef){
    .Instance = I2C1,
    .Init = {
      .Timing = 0xF0110707,
      .OwnAddress1 = 0xAA,
      .AddressingMode = I2C_ADDRESSINGMODE_7BIT,
      .GeneralCallMode = I2C_GENERALCALL_ENABLE,
    },
  };
  HAL_I2C_Init(&i2c1);

  HAL_NVIC_SetPriority(I2C1_IRQn, 2, 0);
  HAL_NVIC_EnableIRQ(I2C1_IRQn);
  HAL_I2C_EnableListen_IT(&i2c1);

  // ======== I2C 2 (encoder) ========
  gpio_init.Pin = GPIO_PIN_11 | GPIO_PIN_12;
  gpio_init.Mode = GPIO_MODE_AF_PP;
  gpio_init.Alternate = GPIO_AF6_I2C2;
  gpio_init.Pull = GPIO_NOPULL;
  gpio_init.Speed = GPIO_SPEED_FREQ_HIGH;
  HAL_GPIO_Init(GPIOA, &gpio_init);

  __HAL_RCC_I2C2_CLK_ENABLE();
  HAL_I2CEx_EnableFastModePlus(I2C_FASTMODEPLUS_I2C2);
  i2c2 = (I2C_HandleTypeDef){
    .Instance = I2C2,
    .Init = {
      // AS5600 datasheet p. 12
      // f_SCL <= 1 MHz, t_LOW >= 0.5 us, t_HIGH >= 0.26 us

      // RM0454 Rev 5, pp. 711, 726, 738 (examples), 766
      // APB = 64 MHz
      // PRESC = 3 (1 / (64 MHz / (3+1)) = 0.0625 us)
      // SCLH = SCLL = 7 (0.5 us) -> f_SCL = 1 MHz
      // SCLDEL = 1, SDADEL = 1
      .Timing = 0x30110707,
      .OwnAddress1 = 0x00,
      .AddressingMode = I2C_ADDRESSINGMODE_7BIT,
    },
  };
  HAL_I2C_Init(&i2c2);

  HAL_StatusTypeDef enc_ready = HAL_I2C_IsDeviceReady(&i2c2, 0x36 << 1, 3, 1000);
  swv_printf("encoder ready status: %d\n", (int)enc_ready);
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

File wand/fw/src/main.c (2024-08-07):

#include <stm32g0xx_hal.h>
#include <math.h>
#include <stdarg.h>
#include <stdbool.h>
#include <stdint.h>
#include <stdio.h>
#include "../../../testdrive/cli/ekf.h"
#include "../../../testdrive/cli/geom.h"
#include "../../../testdrive/cli/elli_fit.h"

#define BMI_CS_PIN  GPIO_PIN_3
#define BMI_CS_PORT GPIOA
#define nRF_CS_PIN  GPIO_PIN_11
#define nRF_CS_PORT GPIOA
#define nRF_CE_PIN  GPIO_PIN_12
#define nRF_CE_PORT GPIOA
#define VDDSUB_G_PIN  GPIO_PIN_3
#define VDDSUB_G_PORT GPIOA
#define MOTOR_G_PIN   GPIO_PIN_4
#define MOTOR_G_PORT  GPIOA

// #define RELEASE
#ifndef RELEASE
#define _release_inline
static uint8_t swv_buf[256];
static size_t swv_buf_ptr = 0;
__attribute__ ((noinline, used))
void swv_trap_line()
{
  *(volatile char *)swv_buf;
}
static inline void swv_putchar(uint8_t c)
{
  // ITM_SendChar(c);
  if (c == '\n') {
    swv_buf[swv_buf_ptr >= sizeof swv_buf ?
      (sizeof swv_buf - 1) : swv_buf_ptr] = '\0';
    swv_trap_line();
    swv_buf_ptr = 0;
  } else if (++swv_buf_ptr <= sizeof swv_buf) {
    swv_buf[swv_buf_ptr - 1] = c;
  }
}
static void swv_printf(const char *restrict fmt, ...)
{
  char s[256];
  va_list args;
  va_start(args, fmt);
  int r = vsnprintf(s, sizeof s, fmt, args);
  for (int i = 0; i < r && i < sizeof s - 1; i++) swv_putchar(s[i]);
  if (r >= sizeof s) {
    for (int i = 0; i < 3; i++) swv_putchar('.');
    swv_putchar('\n');
  }
}
#else
#define _release_inline inline
#define swv_printf(...)
#endif

SPI_HandleTypeDef spi1 = { 0 }, spi2 = { 0 };
UART_HandleTypeDef uart2;

#pragma GCC optimize("O3")
static inline void spi1_transmit(uint8_t *data, size_t size)
{
  HAL_SPI_Transmit(&spi1, data, size, 1000); return;
/*
  for (int i = 0; i < size; i++) {
    while (!(SPI1->SR & SPI_SR_TXE)) { }
    SPI1->DR = data[i];
  }
  while (!(SPI1->SR & SPI_SR_TXE)) { }
  while ((SPI1->SR & SPI_SR_BSY)) { }
  // Clear OVR flag
  (void)SPI1->DR;
  (void)SPI1->SR;
*/
}

static inline void spi2_transmit(const uint8_t *data, size_t size)
{
  HAL_SPI_Transmit(&spi2, (uint8_t *)data, size, 1000); return;
}
static inline void spi2_receive(uint8_t *data, size_t size)
{
  for (int i = 0; i < size; i++) data[i] = 0xAA;
  HAL_SPI_Receive(&spi2, data, size, 1000);
}
static _release_inline uint8_t bmi270_read_reg(uint8_t reg)
{
  uint8_t data[2] = {0x80 | reg};
  HAL_GPIO_WritePin(BMI_CS_PORT, BMI_CS_PIN, 0);
  spi2_transmit(data, 1);
  spi2_receive(data, 2);
  HAL_GPIO_WritePin(BMI_CS_PORT, BMI_CS_PIN, 1);
  return data[1];
}
static _release_inline void bmi270_write_reg(uint8_t reg, uint8_t value)
{
  uint8_t data[2] = {reg, value};
  HAL_GPIO_WritePin(BMI_CS_PORT, BMI_CS_PIN, 0);
  spi2_transmit(data, 2);
  HAL_GPIO_WritePin(BMI_CS_PORT, BMI_CS_PIN, 1);
  // 2 µs delay
}
static _release_inline void bmi270_read_burst(uint8_t reg, uint8_t *data, uint32_t len)
{
  HAL_GPIO_WritePin(BMI_CS_PORT, BMI_CS_PIN, 0);
  uint8_t data_byte = {0x80 | reg};
  spi2_transmit(&data_byte, 1);
/*
  // XXX: This works differently from expected – the first actual data byte missing?
  spi2_receive(&data_byte, 1);  // Dummy byte
  swv_printf("[%02x]", (int)data_byte);
  spi2_receive(data, len);
  for (int i = 0; i < len; i++) swv_printf(" (%02x)", (int)data[i]);
*/
  static uint8_t buf[32];
  spi2_receive(buf, len + 1);
  for (int i = 0; i < len; i++) data[i] = buf[i + 1];
  HAL_GPIO_WritePin(BMI_CS_PORT, BMI_CS_PIN, 1);
}
static _release_inline void bmi270_write_burst(const uint8_t *data, uint32_t len)
{
  HAL_GPIO_WritePin(BMI_CS_PORT, BMI_CS_PIN, 0);
  spi2_transmit(data, len);
  HAL_GPIO_WritePin(BMI_CS_PORT, BMI_CS_PIN, 1);
}
static const uint8_t bmi270_config_file[] = {
  0x5E,
  0xc8, 0x2e, 0x00, 0x2e, 0x80, 0x2e, 0x3d, 0xb1, 0xc8, 0x2e, 0x00, 0x2e, 0x80, 0x2e, 0x91, 0x03, 0x80, 0x2e, 0xbc,
  0xb0, 0x80, 0x2e, 0xa3, 0x03, 0xc8, 0x2e, 0x00, 0x2e, 0x80, 0x2e, 0x00, 0xb0, 0x50, 0x30, 0x21, 0x2e, 0x59, 0xf5,
  0x10, 0x30, 0x21, 0x2e, 0x6a, 0xf5, 0x80, 0x2e, 0x3b, 0x03, 0x00, 0x00, 0x00, 0x00, 0x08, 0x19, 0x01, 0x00, 0x22,
  0x00, 0x75, 0x00, 0x00, 0x10, 0x00, 0x10, 0xd1, 0x00, 0xb3, 0x43, 0x80, 0x2e, 0x00, 0xc1, 0x80, 0x2e, 0x00, 0xc1,
  0x80, 0x2e, 0x00, 0xc1, 0x80, 0x2e, 0x00, 0xc1, 0x80, 0x2e, 0x00, 0xc1, 0x80, 0x2e, 0x00, 0xc1, 0x80, 0x2e, 0x00,
  0xc1, 0x80, 0x2e, 0x00, 0xc1, 0x80, 0x2e, 0x00, 0xc1, 0x80, 0x2e, 0x00, 0xc1, 0x80, 0x2e, 0x00, 0xc1, 0x80, 0x2e,
  0x00, 0xc1, 0x80, 0x2e, 0x00, 0xc1, 0x80, 0x2e, 0x00, 0xc1, 0x80, 0x2e, 0x00, 0xc1, 0x80, 0x2e, 0x00, 0xc1, 0x80,
  0x2e, 0x00, 0xc1, 0x80, 0x2e, 0x00, 0xc1, 0x80, 0x2e, 0x00, 0xc1, 0x80, 0x2e, 0x00, 0xc1, 0x80, 0x2e, 0x00, 0xc1,
  0x80, 0x2e, 0x00, 0xc1, 0x80, 0x2e, 0x00, 0xc1, 0x80, 0x2e, 0x00, 0xc1, 0x80, 0x2e, 0x00, 0xc1, 0x80, 0x2e, 0x00,
  0xc1, 0x80, 0x2e, 0x00, 0xc1, 0x80, 0x2e, 0x00, 0xc1, 0x80, 0x2e, 0x00, 0xc1, 0x80, 0x2e, 0x00, 0xc1, 0x80, 0x2e,
  0x00, 0xc1, 0x80, 0x2e, 0x00, 0xc1, 0x80, 0x2e, 0x00, 0xc1, 0x80, 0x2e, 0x00, 0xc1, 0x80, 0x2e, 0x00, 0xc1, 0x80,
  0x2e, 0x00, 0xc1, 0x80, 0x2e, 0x00, 0xc1, 0x80, 0x2e, 0x00, 0xc1, 0x80, 0x2e, 0x00, 0xc1, 0x80, 0x2e, 0x00, 0xc1,
  0x80, 0x2e, 0x00, 0xc1, 0x80, 0x2e, 0x00, 0xc1, 0xe0, 0x5f, 0x00, 0x00, 0x00, 0x00, 0x01, 0x00, 0x00, 0x00, 0x00,
  0x00, 0x00, 0x00, 0x00, 0x00, 0x00, 0x00, 0x92, 0x00, 0x00, 0x00, 0x00, 0x00, 0x00, 0x00, 0x00, 0x00, 0x00, 0x00,
  0x00, 0x00, 0x00, 0x00, 0x00, 0x00, 0x08, 0x19, 0x00, 0x00, 0x88, 0x00, 0x00, 0x00, 0x00, 0x00, 0x00, 0x00, 0x05,
  0xe0, 0xaa, 0x38, 0x05, 0xe0, 0x90, 0x30, 0xfa, 0x00, 0x96, 0x00, 0x4b, 0x09, 0x11, 0x00, 0x11, 0x00, 0x02, 0x00,
  0x2d, 0x01, 0xd4, 0x7b, 0x3b, 0x01, 0xdb, 0x7a, 0x04, 0x00, 0x3f, 0x7b, 0xcd, 0x6c, 0xc3, 0x04, 0x85, 0x09, 0xc3,
  0x04, 0xec, 0xe6, 0x0c, 0x46, 0x01, 0x00, 0x27, 0x00, 0x19, 0x00, 0x96, 0x00, 0xa0, 0x00, 0x01, 0x00, 0x0c, 0x00,
  0xf0, 0x3c, 0x00, 0x01, 0x01, 0x00, 0x03, 0x00, 0x01, 0x00, 0x0e, 0x00, 0x00, 0x00, 0x32, 0x00, 0x05, 0x00, 0xee,
  0x06, 0x04, 0x00, 0xc8, 0x00, 0x00, 0x00, 0x04, 0x00, 0xa8, 0x05, 0xee, 0x06, 0x00, 0x04, 0xbc, 0x02, 0xb3, 0x00,
  0x85, 0x07, 0x00, 0x00, 0x00, 0x00, 0x00, 0x00, 0x00, 0x00, 0x00, 0x00, 0x00, 0x00, 0x00, 0x00, 0x00, 0x00, 0x00,
  0x00, 0x00, 0x00, 0xb4, 0x00, 0x01, 0x00, 0xb9, 0x00, 0x01, 0x00, 0x98, 0x00, 0x00, 0x00, 0x00, 0x00, 0x00, 0x00,
  0x00, 0x00, 0x01, 0x00, 0x80, 0x00, 0x04, 0x00, 0x00, 0x00, 0x00, 0x00, 0x00, 0x00, 0x00, 0x00, 0x00, 0x00, 0x00,
  0x00, 0x00, 0x00, 0x00, 0x00, 0x00, 0x00, 0x00, 0x00, 0x00, 0x00, 0x00, 0x00, 0x00, 0x00, 0x00, 0x00, 0x00, 0x00,
  0x00, 0x00, 0x00, 0x00, 0x00, 0x00, 0x00, 0x00, 0x00, 0x00, 0x00, 0x00, 0x00, 0x00, 0x00, 0x00, 0x00, 0x00, 0x00,
  0x00, 0x00, 0x00, 0x00, 0x00, 0x00, 0x00, 0x00, 0x00, 0x00, 0x00, 0x00, 0x00, 0x00, 0x00, 0x00, 0x00, 0x00, 0x00,
  0x00, 0x00, 0x00, 0x00, 0x00, 0x00, 0x00, 0x00, 0x00, 0x00, 0x00, 0x00, 0x80, 0x2e, 0x00, 0xc1, 0xfd, 0x2d, 0xde,
  0x00, 0xeb, 0x00, 0xda, 0x00, 0x00, 0x0c, 0xff, 0x0f, 0x00, 0x04, 0xc0, 0x00, 0x5b, 0xf5, 0xc9, 0x01, 0x1e, 0xf2,
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

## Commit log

2023-12-25 🎉 Create ECAD project for pendulum test drive
    [Pendu.kicad_pcb, Pendu.kicad_sch]
2023-12-26 Finish testdrive schematic
    [Pendu.kicad_sch]
2023-12-26 Revise testdrive schematic, revert to unified VDD
    [Pendu.kicad_sch]
2023-12-26 Finish PCB layout and routing (schematic fix to-do)
    [Pendu.kicad_pcb, Pendu.kicad_sch]
2023-12-27 Fix circuit design, submit for fabrication
    [Pendu.kicad_pcb, Pendu.kicad_sch]
2024-01-01 Add a glass ball holder 3D model
    [2x_D7_Holder.FCStd]
2024-01-05 Revise glass holder part
    [2x_D7_Holder.FCStd]
2024-01-08 Communicate with BMI270 through SPI
2024-01-08 Coloured lights by IMU data
2024-01-09 Add filter test
2024-01-09 Add fixed-point version of the filter
2024-01-10 Incorporate complementary filter into firmware
2024-01-13 Create schematic for updated wand hardware
    [Wand.kicad_pcb, Wand.kicad_sch]
2024-01-13 (WIP) Wand PCB design
    [Wand.kicad_pcb, Wand.kicad_sch]
2024-01-13 Revise wand hardware design
    [Wand.kicad_pcb]
2024-01-13 Read data from magnetic sensor
2024-01-13 Continuously read from magnetic sensor
2024-01-15 Revise silkscreen text; submit for fabrication
    [Wand.kicad_pcb]
2024-01-17 Add flyback diode reminder
    [Wand.kicad_sch]
2024-01-18 Add key bar test model
    [Bar_1.scad]
2024-01-19 Pass magnetometer data to client
2024-01-19 Visualise magnetometer and accelerometer values
2024-01-19 Plot velocity of spherical pendulum
2024-01-20 Calibrate accelerometer w.r.t. gravity
2024-01-20 Correctly fit the ellipsoid with the device
    [main.cc]
2024-01-21 Separate magnetometer calibration from accelerometer
2024-01-21 Complementary filter for orientation
2024-01-21 Correct x-y heading estimation with tilt angle
    [main.cc]
2024-01-21 (WIP) Print calibrated IMU readings?
2024-01-21 Estimate heading from gyroscope data with EKF
2024-01-21 Incorporate filtered heading into test client
2024-01-22 Test filter performance on hardware
2024-01-22 Properly visualise filtered phase output
2024-01-22 Fix incorrect markings in ECAD files
    [Wand.kicad_pcb, Wand.kicad_sch]
2024-01-22 Add mallet schematic
    [Mallet.kicad_pcb, Mallet.kicad_sch]
2024-01-23 Finish mallet PCB
    [Mallet.kicad_pcb, Mallet.kicad_sch]
2024-01-23 Add mallet central hardware design
    [LTC4311CSC6#TRPBF.stp, Mallet_Cen.kicad_pcb, Mallet_Cen.kicad_sch]
2024-01-23 Revise central module hardware design
    [Mallet_Cen.kicad_pcb, Mallet_Cen.kicad_sch, Wand.kicad_pcb]
2024-01-23 Revise central module PCB for JLCPCB QR code
    [Mallet_Cen.kicad_pcb]
2024-01-23 Fix incorrect pin assignment for external RF module; submit for fab
    [Mallet_Cen.kicad_pcb, Mallet_Cen.kicad_sch]
2024-01-25 Activate vibration motor
2024-01-25 Blink LED with all three channels
2024-01-26 Pull down motor NMOS gate for stable booting
    [Wand.kicad_sch]
2024-01-27 Revise wand PCB as per fab. clearance requirements
    [Wand.kicad_pcb]
2024-01-30 Fix firmware; start rotating
    [main.c]
2024-01-30 Add firmware for the central unit, blinking LED
2024-01-30 Add mallet holder part design
    [Mallet_Holder.FCStd]
2024-01-30 (WIP) Correct filtering in the firmware
    [main.c, main.cc]
2024-01-31 Add metal bars mechanical design; submit for fab
    [Bars.scad]
2024-01-31 Tune EKF on device
2024-01-31 Automatic gravity calibration and further filter tuning
2024-01-31 Functional I2C communication
2024-02-01 Revise mechanical parts for mallet unit
    [Elev_Ring.FCStd, Mallet_Holder.FCStd]
2024-02-01 Improved filter again
2024-02-01 Calibrate motor
2024-02-02 Retry nRF24L01+ communication on startup errors
    [main.c]
2024-02-02 Save power by reducing torque when idle
2024-02-03 Revise testrun behvaiour (blink fast on I2C error)
    [main.c]
2024-02-04 Revise mallet holder mechanical parts, again
    [Elev_Ring.FCStd, Mallet_Holder.FCStd]
2024-02-04 Emulate PWM for LED blue channel
2024-02-04 Fix emulated PWM cannot reach 0% duty
    [main.c]
2024-02-04 Improve consistency of emulated PWM IRQ subroutine
2024-02-04 Blink LED on stroke
2024-02-05 Auto-play on wand; increase wand LED brightness
2024-04-09 Test program memory usage on STM32L011
2024-04-26 🚧 Revise schematic; use a separate MCU for the bob
    [Wand.kicad_sch]
2024-04-26 Finish revision of schematic
    [Wand.kicad_sch]
2024-04-26 🚧 Updating circuit board design
    [Wand.kicad_pcb]
2024-04-29 Finish wand board update
    [Wand.kicad_pcb]
2024-04-30 Finishing touches of board revision; submit for fab
    [Wand.kicad_pcb]
2024-05-07 Add wand casing CAD model
    [Handle.FCStd]
2024-05-08 🚧 Revise firmware
2024-05-08 🎉 Revise paper 📸
2024-05-09 Is this perfectionism, or is this just 🍊🥤🌊
2024-07-16 🚧 Mark possible places for corrections in firmware
    [main.c]
2024-08-02 🚧 Attempts at communicating with SPI devices (defect unknown)
2024-08-02 🚧 UART correctly receives, but data is incorrect?
    [main.c]
2024-08-02 🚧 Still
2024-08-03 Correctly receiving UART signals
    [main.c]
2024-08-03 🚧 Bidirectional UART?
2024-08-03 Resolve issues with SPI
    [main.c]
2024-08-03 Read-outs from IMU
2024-08-07 Working bidirectional UART communication
2024-08-07 Implement minimal `vsnprintf` to reduce ROM footprint
2024-08-07 Reduce ROM footprint of UART subroutines
2024-08-07 Send sensor data from the 'L0 to the 'G0
2024-08-07 Receive and broadcast sensor data!
2024-08-07 Replace BMI270 configuration with a minimal version
    [main.c]
